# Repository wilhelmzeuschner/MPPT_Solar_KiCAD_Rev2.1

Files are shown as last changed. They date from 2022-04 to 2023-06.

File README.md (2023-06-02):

# Maximum Power Point Tracker for Solar Panels

This project was done as part of my studies at university. It's intended use case is for my [University's solar boat team](https://www.hs-emden-leer.de/studierende/fachbereiche/technik/projekte/solarboot).

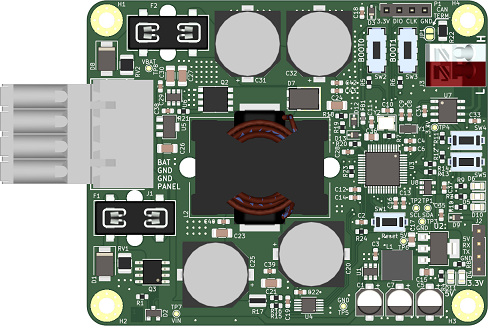
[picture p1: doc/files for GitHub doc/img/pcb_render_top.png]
render 3D Render


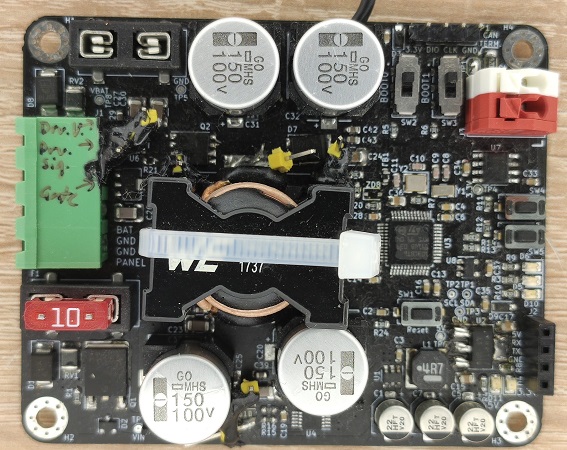
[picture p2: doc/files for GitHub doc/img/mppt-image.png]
Photo of the PCB


## Technical Overview:

- 150W input power
- Boost Converter: Uin < Uout
- STM32 Microcontroller
- CAN Communications (software support lacking as of April 2022)

## How to use this repo:

### Schematic:
The schematic can be found here: https://github.com/wilhelmzeuschner/MPPT_Solar_KiCAD_Rev2.1/blob/main/pcb/export/Schematic.pdf

### Code:
The source code is located here: https://github.com/wilhelmzeuschner/MPPT_Solar_KiCAD_Rev2.1/tree/main/code/MPPT_Main

Platform IO was used for programming, just clone the repo and open the folder / workspace. The Arduino framework was used for the firmware.

### PCB:
The PCB was designed with KiCAD V6, the files are located here: https://github.com/wilhelmzeuschner/MPPT_Solar_KiCAD_Rev2.1/tree/main/pcb/kicad_files

### Bill of Materials (BOM):
The BOM file is also provided, although some parts are not available as of April 2022 due to the semiconductor shortage.
https://github.com/wilhelmzeuschner/MPPT_Solar_KiCAD_Rev2.1/tree/main/bom

### CAD Files for a 3D-printable Case:
https://github.com/wilhelmzeuschner/MPPT_Solar_KiCAD_Rev2.1/tree/main/cad

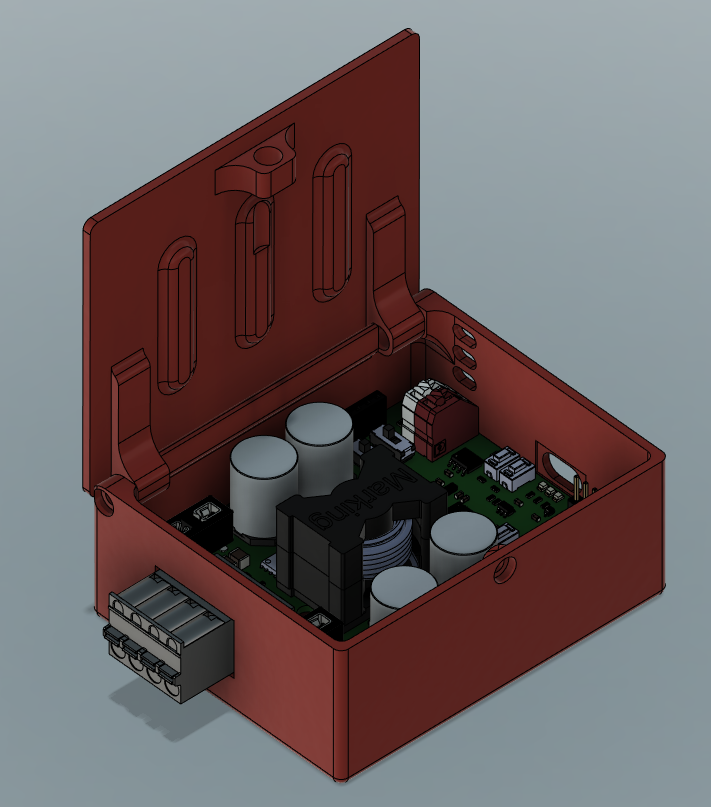
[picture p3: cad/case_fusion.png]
Case


## Further documentation:

This project was documented extensively. The technical report can be found here:
https://github.com/wilhelmzeuschner/MPPT_Solar_KiCAD_Rev2.1/blob/main/doc/latex/pdf/Projektarbeit_MPPT_Wilhelm_Zeuschner_GitHub.pdf

### License:

MIT License

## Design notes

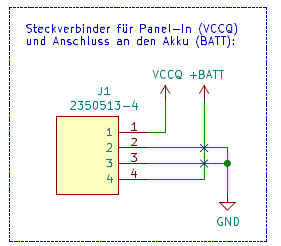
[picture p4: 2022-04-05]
doc/latex/img/schematics/all sections of the project/schem_main_pwr_conn.png

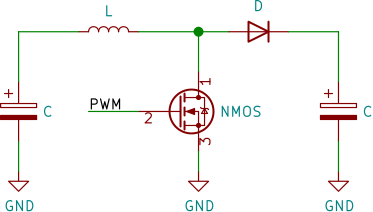
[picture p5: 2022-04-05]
doc/latex/img/schematics/boost_converter_example/g668.png

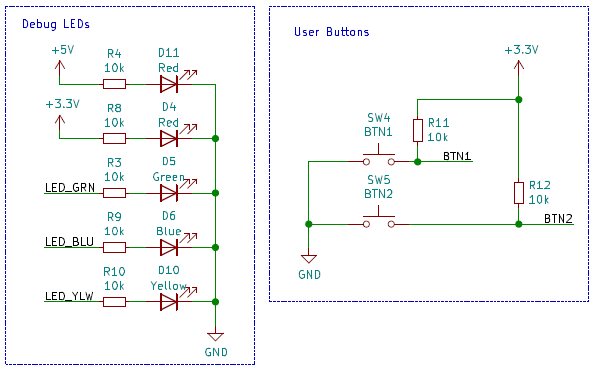
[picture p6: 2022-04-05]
doc/latex/img/schematics/all sections of the project/schem_leds_buttons.png

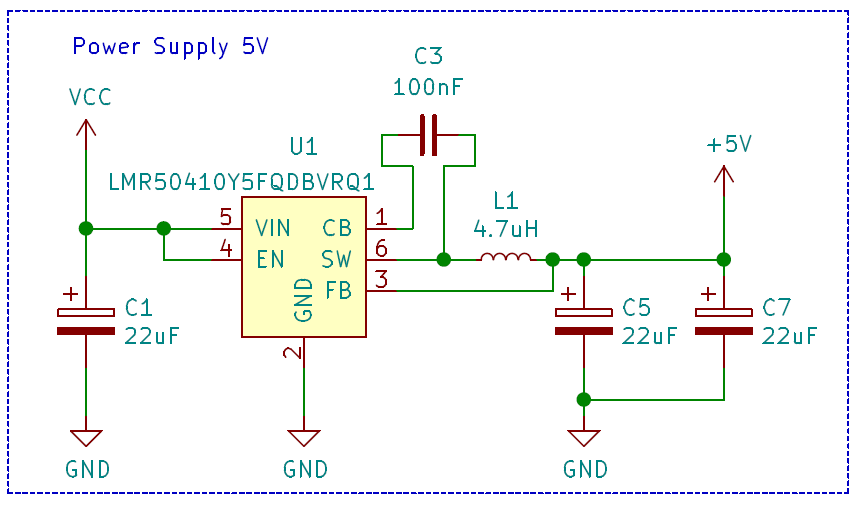
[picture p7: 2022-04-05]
doc/latex/img/schematics/all sections of the project/schem_5v_buck.png

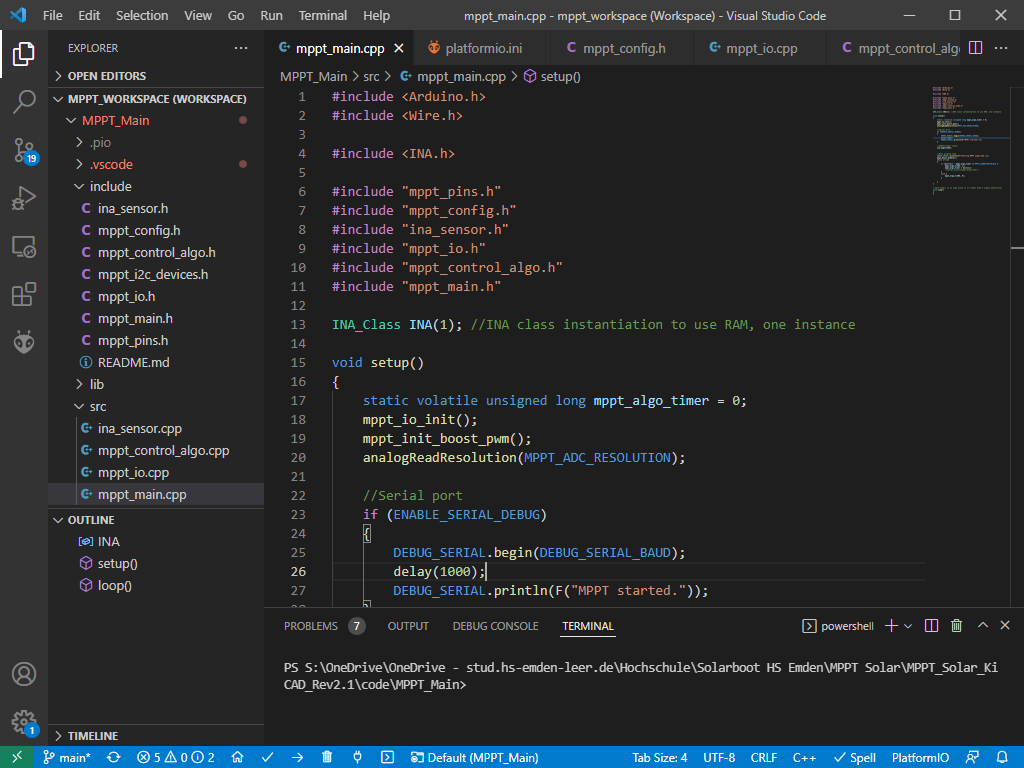
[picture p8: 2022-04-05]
doc/latex/img/sw/sw_pio_overview.png

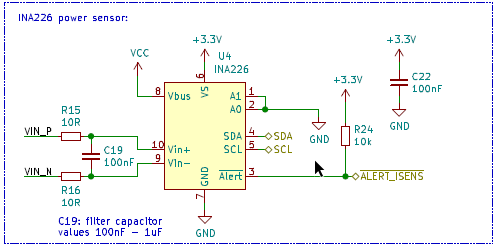
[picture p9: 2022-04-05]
doc/latex/img/schematics/all sections of the project/schem_ina.png

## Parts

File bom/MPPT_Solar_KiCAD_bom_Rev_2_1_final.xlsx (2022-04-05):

Quantity Per PCB | References | Value | Digikey Part No | Manufacturer Part Number | Note | Component | Description | Part | Footprint | Datasheet | Config
4 | C8 C9 C10 C11 | 24pF | 1276-1761-1-ND | 80-C0603C240G1HACTU |  | 1 | Unpolarized capacitor, small symbol | C_Small | C_0603_1608Metric | https://www.digikey.ch/product-detail/en/samsung-electro-mechanics/CL10C240JB8NNNC/1276-1761-1-ND/3889847
1 | C28 | 1nF | 399-12989-1-ND | C0603C102J5RACAUTO |  | 2 | Unpolarized capacitor, small symbol | C_Small | C_0603_1608Metric | https://www.digikey.ch/product-detail/en/kemet/C0603C102J5RACAUTO/399-12989-1-ND/5762271
15 | C2 C3 C4 C6 C12 C13 C14 C16 C18 C19 C22 C33 C34 C35 C37 | 100nF | 1276-CL10B104KB8NNNLCT-ND | LMK063C6104KP-F |  | 3 | Unpolarized capacitor, small symbol | C_Small | C_0603_1608Metric | https://www.digikey.ch/product-detail/en/samsung-electro-mechanics/CL10B104KB8NNNL/1276-CL10B104KB8NNNLCT-ND/10320686
3 | C15 C17 C36 | 4.7uF | 1276-1244-1-ND | 885012107013 |  | 4 | Unpolarized capacitor | C | C_0805_2012Metric | https://www.digikey.ch/product-detail/en/samsung-electro-mechanics/CL21A475KAQNNNE/1276-1244-1-ND/3889330
3 | C1 C5 C7 | 22uF | PCE5022CT-ND | 865080643008 |  | 5 | Polarized capacitor | CP | CP_Elec_5x5.9 | https://www.digikey.de/product-detail/en/panasonic-electronic-components/EEE-FT1H220AR/PCE5022CT-ND/2652077
6 | C29 C38 C39 C40 C42 C43 | 100V 100nF | 587-6323-1-ND | CL10B104KC8NNNC |  | 6 | Unpolarized capacitor, small symbol | C_Small | C_0603_1608Metric | https://www.digikey.ch/product-detail/en/taiyo-yuden/HMK107B7104MA-T/587-6323-1-ND/9949909
4 | C20 C25 C31 C32 | 100V 150uF | 565-5086-1-ND | EMHS101ARA151MKG5S |  | 7 | Polarized capacitor, small symbol | CP_Small | CAPAE1300X1650N | https://www.digikey.de/product-detail/en/united-chemi-con/EMHS800GRA241MKG5S/565-5090-1-ND/8558344
6 | C21 C23 C24 C26 C27 C30 | 100V 1uF | 587-5021-1-ND | HMK316BJ105KL-T |  | 8 | Unpolarized capacitor, small symbol | C_Small | C_1210_3225Metric_Pad1.42x2.65mm_HandSolder | https://www.digikey.ch/product-detail/en/taiyo-yuden/HMK316BJ105KL-T/587-5021-1-ND/6563864
1 | D6 | Blue | 732-4982-1-ND | 150080BS75000 |  | 9 | Light emitting diode | LED | LED_0805_2012Metric | https://www.digikey.de/product-detail/en/wÃ¼rth-elektronik/150080BS75000/732-4982-1-ND/4489910
1 | D5 | Green | 732-4983-1-ND | 150080GS75000 |  | 10 | Light emitting diode | LED | LED_0805_2012Metric | https://www.digikey.de/product-detail/en/wÃ¼rth-elektronik/150080GS75000/732-4983-1-ND/4489913
1 | D2 | MMBZ5245BLT1G | MMBZ5245BLT1GOSCT-ND | MMBZ5245BLT1G |  | 11 | Zener diode | D_Zener | D_SOT-23_ANK | https://www.digikey.de/product-detail/en/on-semiconductor/MMBZ5245BLT1G/MMBZ5245BLT1GOSCT-ND/1139860
2 | D4 D11 | Red | 732-4984-1-ND | 150080RS75000 |  | 12 | Light emitting diode | LED | LED_0805_2012Metric | https://www.digikey.de/product-detail/en/wÃ¼rth-elektronik/150080RS75000/732-4984-1-ND/4489916
2 | D1 D8 | SMBJ58A | SMBJ58ALFCT-ND | SMBJ58A |  | 13 | Zener diode | D_Zener | D_SMB | https://www.digikey.de/product-detail/en/littelfuse-inc/SMBJ58A/SMBJ58ALFCT-ND/762804
2 | D3 D9 | SS16HE | SS16HECT-ND | SS16HE |  | 14 | Schottky diode, small symbol | D_Schottky_Small | D_SOD-323_HandSoldering | https://www.digikey.de/product-detail/en/on-semiconductor/SS16HE/SS16HECT-ND/6009714
2 | D7 | TSPB20U80S S1G | TSPB20U80SS1GCT-ND | TSPB20U80S S1G |  | 15 | Schottky diode, anode on pins 1 and 2 | V15P8HM3_A_H | TO-277A | https://www.digikey.de/product-detail/en/taiwan-semiconductor-corporation/TSPB20U80S-S1G/TSPB20U80SS1GCT-ND/7360696
1 | D10 | Yellow | 732-4987-1-ND | 150080YS75000 |  | 16 | Light emitting diode | LED | LED_0805_2012Metric | https://www.digikey.de/product-detail/en/wÃ¼rth-elektronik/150080YS75000/732-4987-1-ND/4489925
2 | F1 F2 | 3588TR | 36-3588CT-ND | 3588TR | Fuse: 0297010.WXNV https://www.digikey.de/product-detail/en/littelfuse-inc/0297010-WXNV/F991-ND/146591 | 17 |  | 3588TR | 3588TR | https://www.digikey.de/product-detail/en/keystone-electronics/3588TR/36-3588CT-ND/4772085
1 | FB1 | Ferrite_Bead | 490-9701-1-ND | BLM18TG102TN1D |  | 18 | Ferrite bead, small symbol | Ferrite_Bead_Small | L_0603_1608Metric | https://www.digikey.de/product-detail/en/murata-electronics/BLM18TG102TN1D/490-9701-1-ND/4934841
1 | J1 | 2350513-4 | A145374-ND | 2350513-4 | Counterpart: A145365-ND (2350397-4) | 19 | Pluggable Terminal Blocks 4pos Header 90 Deg 5.0mmTail Lgth 4.5mm | 2350513-4 | SHDRRA4W110P0X500_1X4_2160X830X1230P | https://www.digikey.de/product-detail/en/te-connectivity-amp-connectors/2350513-4/A145374-ND/10415924
1 | J3 | CAN | 277-8591-ND | 1713017 |  | 20 | Generic connector, single row, 01x02, script generated (kicad-library-utils/schlib/autogen/connector/) | Conn_01x02 | 1713017 | https://www.digikey.de/product-detail/en/phoenix-contact/1713017/277-8591-ND/2513977
1 | J2 | UART | 2057-RS1-04-G-ND | RS1-04-G |  | 21 | Generic connector, single row, 01x04, script generated (kicad-library-utils/schlib/autogen/connector/) | Conn_01x04 | PinHeader_1x04_P2.54mm_Vertical | https://www.digikey.de/product-detail/en/adam-tech/RS1-04-G/2057-RS1-04-G-ND/9829303
1 | L1 | 4.7uH | 587-2943-1-ND | NRS6028T4R7MMGK |  | 22 | Inductor, small symbol | L_Small | 60x60mm_Inductor | https://www.digikey.de/product-detail/en/taiyo-yuden/NRS6028T4R7MMGK/587-2943-1-ND/2666048
1 | L2 | 68uH | 732-11708-ND | 74437429203680 |  | 23 | 74437429203680 Inductor with ferrite core | 68uH | 74437429203680 | https://www.digikey.de/products/en?keywords=74437429203680
1 | P1 | SWD_Prog_port | 2057-RS1-04-G-ND | RS1-04-G |  | 24 |  | SWD_Prog_port | PinSocket_1x04_P2.54mm_Vertical | https://www.digikey.de/product-detail/en/adam-tech/RS1-04-G/2057-RS1-04-G-ND/9829303
1 | Q1 | ATP302 | ATP302-TL-HOSCT-ND | ATP302-TL-H |  | 25 | P-MOSFET transistor, gate/drain/source | Q_PMOS_GDS | ATPAK-2 | https://www.digikey.de/product-detail/en/on-semiconductor/ATP302-TL-H/ATP302-TL-HOSCT-ND/5801683
2 | Q2 | TPH2R408QM,L1Q | 264-TPH2R408QML1QCT-ND | TPH2R408QM,L1Q |  | 26 |  | TPH2R608NH | SOP_ADVANCE | https://www.digikey.de/product-detail/en/toshiba-semiconductor-and-storage/TPH2R408QM-L1Q/264-TPH2R408QML1QCT-ND/11658238
1 | R21 | 0R | 311-0.0HRCT-ND | RC0603FR-070RL |  | 27 | Resistor, small symbol | R_Small | R_0603_1608Metric | https://www.digikey.de/product-detail/en/yageo/RC0603FR-070RL/311-0-0HRCT-ND/4340584
1 | R17 | 10mR | CFG0612-FX-R010ELFCT-ND | CFG0612-FX-R010ELF |  | 28 | Resistor | R | R_0612_1632Metric | https://www.digikey.de/product-detail/en/bourns-inc/CFG0612-FX-R010ELF/CFG0612-FX-R010ELFCT-ND/9924214
3 | R15 R16 R23 | 10R | RMCF0603FT10R0CT-ND | RMCF0603FT10R0 |  | 29 | Resistor, small symbol | R_Small | R_0603_1608Metric | https://www.digikey.de/product-detail/en/stackpole-electronics-inc/RMCF0603FT10R0/RMCF0603FT10R0CT-ND/1942943
1 | R22 | 120R | 311-120FRCT-ND | RC1206FR-07120RL |  | 30 | Resistor, small symbol | R_Small | R_1206_3216Metric | https://www.digikey.de/product-detail/en/yageo/RC1206FR-07120RL/311-120FRCT-ND/731470
1 | R20 | 1k | 541-3949-1-ND | CRCW06031K00FKEAC |  | 31 | Resistor, small symbol | R_Small | R_0603_1608Metric | https://www.mouser.de/ProductDetail/Vishay-Dale/CRCW06031K00FKEAC
15 | R1 R3 R4 R5 R6 R8 R9 R10 R11 R12 R13 R14 R18 R19 R24 | 10k | 311-10.0KHRCT-ND | RC0603FR-0710KL |  | 32 | Resistor, small symbol | R_Small | R_0603_1608Metric | https://www.mouser.de/ProductDetail/Yageo/RC0603FR-0710KL
1 | R7 | 1M | 311-1.00MHRCT-ND | RC0603FR-071ML |  | 33 | Resistor, small symbol | R_Small | R_0603_1608Metric | https://www.mouser.de/ProductDetail/Yageo/RC0603FR-071ML
2 | RV1 RV2 | V60MLA1210N | F3830CT-ND | V60MLA1210NH |  | 34 | Voltage dependent resistor | Varistor | R_1210_3225Metric_Pad1.42x2.65mm_HandSolder | https://www.digikey.de/product-detail/en/littelfuse-inc/V60MLA1210NH/F3830CT-ND/2627750
1 | SW4 | BTN1 | CKN12317-1-ND | CKN12317-1-ND |  | 35 | Push button switch, generic, two pins | SW_Push | SW_SPST_EVQPE1 | https://www.digikey.de/product-detail/en/c-k/PTS636-SM43J-SMTR-LFS/CKN12317-1-ND/10071752
1 | SW5 | BTN2 | CKN12317-1-ND | CKN12317-1-ND |  | 36 | Push button switch, generic, two pins | SW_Push | SW_SPST_EVQPE1 | https://www.digikey.de/product-detail/en/c-k/PTS636-SM43J-SMTR-LFS/CKN12317-1-ND/10071752
1 | SW2 | Boot0 | CKN10723CT-ND | JS202011JCQN |  | 37 | Switch, single pole double throw | SW_SPDT | SW_JS202011JCQN | https://www.digikey.de/product-detail/en/c-k/JS202011JCQN/CKN10723CT-ND/6137637
1 | SW3 | Boot1 | CKN10723CT-ND | JS202011JCQN |  | 38 | Switch, single pole double throw | SW_SPDT | SW_JS202011JCQN | https://www.digikey.de/product-detail/en/c-k/JS202011JCQN/CKN10723CT-ND/6137637
1 | SW1 | Reset | CKN12317-1-ND | CKN12317-1-ND |  | 39 | Push button switch, generic, two pins | SW_Push | SW_SPST_EVQPE1 | https://www.digikey.de/product-detail/en/c-k/PTS636-SM43J-SMTR-LFS/CKN12317-1-ND/10071752
2 | U8 | 24FC01T-I_OT | 24FC01T-I/OTCT-ND | 24FC01T-I/OT |  | 40 | 1KB I2C EEPROM 1MHZ 1.7-5.5V 5-S | 24FC01T-I_OT | SOT-23-5 | https://www.digikey.de/product-detail/en/microchip-technology/24FC01T-I-OT/24FC01T-I-OTCT-ND/9867141
2 | U2 | AP2114HA-3.3TRG1 | AP2114HA-3.3TRG1DICT-ND | AP2114HA-3.3TRG1 |  | 41 |  | AP2114H-3.3TRG1 | SOT-223-3_TabPin2 | https://www.digikey.de/product-detail/en/diodes-incorporated/AP2114HA-3-3TRG1/AP2114HA-3-3TRG1DICT-ND/8545749
2 | U4 | INA226 | 296-29034-1-ND | INA226AIDGSR |  | 42 | High-Side or Low-Side Measurement, Bi-Directional Current and Power Monitor (0-36V) with I2C Compatible Interface, VSSOP-10 | INA226 | VSSOP-10_3x3mm_P0.5mm | https://www.digikey.de/product-detail/en/texas-instruments/INA226AIDGSR/296-29034-1-ND/2687118
2 | U5 | L78L18_SOT89 | 497-7280-1-ND | L78L18ACUTR |  | 43 | Positive 100mA 30V Linear Regulator, Fixed Output 18V, SOT-89 | L78L18_SOT89 | SOT-89-3 | https://www.digikey.de/product-detail/en/stmicroelectronics/L78L18ACUTR/497-7280-1-ND/1883360
2 | U1 | LMR50410Y5FQDBVRQ1 | 296-LMR50410Y5FQDBVRQ1CT-ND | LMR50410Y5FQDBVRQ1 |  | 44 | Buck Switching Regulator IC Positive Fixed 5V 1 Output 1A SOT-23-6 | LMR50410Y5FQDBVRQ1 | SOT-23-6 | https://www.digikey.de/product-detail/en/texas-instruments/LMR50410Y5FQDBVRQ1/296-LMR50410Y5FQDBVRQ1CT-ND/13563137
2 | U7 | NCV7344D13R2G | NCV7344D13R2GOSCT-ND | NCV7344D13R2G |  | 45 | 1/1 Transceiver Half CANbus 8-SOIC | NCV7344D13R2G | SOIC-8_3.9x4.9mm_P1.27mm | https://www.digikey.de/product-detail/en/on-semiconductor/NCV7344D13R2G/NCV7344D13R2GOSCT-ND/9923536
2 | U3 | STM32F103CBT6TR | 497-17380-1-ND | STM32F103CBT6TR |  | 46 | ARM Cortex-M3 MCU, 128KB flash, 20KB RAM, 72MHz, 2-3.6V, 37 GPIO, LQFP-48 | STM32F103CBTx | LQFP-48_7x7mm_P0.5mm | https://www.digikey.de/product-detail/en/stmicroelectronics/STM32F103CBT6TR/497-17380-1-ND/7650389
2 | U6 | UCC27531DBVR | 296-35581-1-ND | UCC27531DBVR |  | 47 | UCC2753x 2.5-A and 5-A, 35-VMAX VDD FET and IGBT Single-Gate Driver | UCC27531DBVR | SOT-23-6 | https://www.digikey.de/product-detail/en/texas-instruments/UCC27531DBVR/296-35581-1-ND/3830022
1 | Y1 | 32.768kHz | SER4076CT-ND | FC-135R 32.7680KF-A3 |  | 48 | Two pin crystal | Crystal | Crystal_SMD_MicroCrystal_CC7V-T1A-2Pin_3.2x1.5mm | https://www.digikey.de/product-detail/en/epson/FC-135R-32-7680KF-A3/SER4076CT-ND/5604232
1 | Y2 | 8MHz | 50-ECS-80-12-33Q-GN-CT-ND | ECS-80-12-33Q-GN-TR |  | 49 | Four pin crystal, GND on pins 2 and 4 | Crystal_GND24 | Crystal_SMD_3225-4Pin_3.2x2.5mm | https://www.digikey.de/product-detail/en/ecs-inc/ECS-80-12-33Q-GN-TR/50-ECS-80-12-33Q-GN-CT-ND/12088513
1 | ZD8 | MM3Z3V3T1G | MM3Z3V3T1GOSCT-ND | MM3Z3V3T1G |  | 50 | Zener diode, small symbol | D_Zener_Small | D_SOD-323 | https://www.digikey.de/product-detail/en/on-semiconductor/MM3Z3V3T1G/MM3Z3V3T1GOSCT-ND/2623467
3 | NA | 0297010.WXNV | F991-ND | 0297010.WXNV | 10A Fuse, 1 extra
2 | NA | 2350397-4 | A145365-ND | 2350397-4 | 4 Position Terminal Block Plug, Female Sockets 0.197" (5.00mm) 180° Free Hanging (In-Line), not on PCB, 1 extra
1 | NA | SMD291AX | SMD291AX-ND | SMD291AX | Leaded No-Clean Solder Paste Sn63Pb37 (63/37) Syringe, 0.53 oz (15g), 5cc
This BOM was created manually and not via the automated export

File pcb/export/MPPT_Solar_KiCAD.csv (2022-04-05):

Reference | Quantity | Value | Footprint | Datasheet | Digikey Part No | Manufacturer Part Number | Config | Note | Description | Digi-Key Part No | Manufacturer Part No
C15 C17 C36 | 3 | 4.7uF | Capacitor_SMD:C_0805_2012Metric | https://www.digikey.ch/product-detail/en/samsung-electro-mechanics/CL21A475KAQNNNE/1276-1244-1-ND/3889330 | 1276-1244-1-ND | 885012107013
C20 C25 C31 C32 | 4 | 100V 150uF | MPPT_Solar_KiCAD:CAPAE1300X1650N | https://www.digikey.de/product-detail/en/united-chemi-con/EMHS800GRA241MKG5S/565-5090-1-ND/8558344 | 565-5086-1-ND | EMHS101ARA151MKG5S
C21 C23 C24 C26 C27 C30 | 6 | 100V 1uF | Capacitor_SMD:C_1206_3216Metric | https://www.digikey.ch/product-detail/en/taiyo-yuden/HMK316BJ105KL-T/587-5021-1-ND/6563864 | 587-5021-1-ND | HMK316BJ105KL-T
C28 | 1 | 1nF | Capacitor_SMD:C_0603_1608Metric | https://www.digikey.ch/product-detail/en/kemet/C0603C102J5RACAUTO/399-12989-1-ND/5762271 | 399-12989-1-ND | C0603C102J5RACAUTO
C29 C38 C39 C40 C42 C43 | 6 | 100V 100nF | Capacitor_SMD:C_0603_1608Metric | https://www.digikey.ch/product-detail/en/taiyo-yuden/HMK107B7104MA-T/587-6323-1-ND/9949909 | 587-6323-1-ND | CL10B104KC8NNNC
C2 C3 C4 C6 C12 C13 C14 C16 C18 C19 C22 C33 C34 C35 C37 | 15 | 100nF | Capacitor_SMD:C_0603_1608Metric | https://www.digikey.ch/product-detail/en/samsung-electro-mechanics/CL10B104KB8NNNL/1276-CL10B104KB8NNNLCT-ND/10320686 | 1276-CL10B104KB8NNNLCT-ND | LMK063C6104KP-F
C1 C5 C7 | 3 | 22uF | Capacitor_SMD:CP_Elec_5x5.9 | https://www.digikey.de/product-detail/en/panasonic-electronic-components/EEE-FT1H220AR/PCE5022CT-ND/2652077 | PCE5022CT-ND | 865080643008
C8 C9 C10 C11 | 4 | 24pF | Capacitor_SMD:C_0603_1608Metric | https://www.digikey.ch/product-detail/en/samsung-electro-mechanics/CL10C240JB8NNNC/1276-1761-1-ND/3889847 | 1276-1761-1-ND | 80-C0603C240G1HACTU
D1 D8 | 2 | SMBJ58A | Diode_SMD:D_SMB | https://www.digikey.de/product-detail/en/littelfuse-inc/SMBJ58A/SMBJ58ALFCT-ND/762804 | SMBJ58ALFCT-ND | SMBJ58A
D10 | 1 | Yellow | LED_SMD:LED_0805_2012Metric | https://www.digikey.de/product-detail/en/würth-elektronik/150080YS75000/732-4987-1-ND/4489925 | 732-4987-1-ND | 150080YS75000
D2 D14 | 2 | MMBZ5245BLT1G | Diode_SMD:D_SOT-23_ANK | https://www.digikey.de/product-detail/en/on-semiconductor/MMBZ5245BLT1G/MMBZ5245BLT1GOSCT-ND/1139860 | MMBZ5245BLT1GOSCT-ND | MMBZ5245BLT1G
D3 D9 D12 D13 | 4 | SS16HE | Diode_SMD:D_SOD-323 | https://www.digikey.de/product-detail/en/on-semiconductor/SS16HE/SS16HECT-ND/6009714 | SS16HECT-ND | SS16HE
D4 D11 | 2 | Red | LED_SMD:LED_0805_2012Metric | https://www.digikey.de/product-detail/en/würth-elektronik/150080RS75000/732-4984-1-ND/4489916 | 732-4984-1-ND | 150080RS75000
D5 | 1 | Green | LED_SMD:LED_0805_2012Metric | https://www.digikey.de/product-detail/en/würth-elektronik/150080GS75000/732-4983-1-ND/4489913 | 732-4983-1-ND | 150080GS75000
D6 | 1 | Blue | LED_SMD:LED_0805_2012Metric | https://www.digikey.de/product-detail/en/würth-elektronik/150080BS75000/732-4982-1-ND/4489910 | 732-4982-1-ND | 150080BS75000
D7 | 1 | TSPB20U80S S1G | Package_TO_SOT_SMD:TO-277A | https://www.digikey.de/product-detail/en/taiwan-semiconductor-corporation/TSPB20U80S-S1G/TSPB20U80SS1GCT-ND/7360696 | TSPB20U80SS1GCT-ND | TSPB20U80S S1G
F1 F2 | 2 | 3588TR | MPPT_Solar_KiCAD:3588TR | https://www.digikey.de/product-detail/en/keystone-electronics/3588TR/36-3588CT-ND/4772085 | 36-3588CT-ND | 3588TR |  | Fuse: 0297010.WXNV https://www.digikey.de/product-detail/en/littelfuse-inc/0297010-WXNV/F991-ND/146591
FB1 | 1 | Ferrite_Bead | Inductor_SMD:L_0603_1608Metric | https://www.digikey.de/product-detail/en/murata-electronics/BLM18TG102TN1D/490-9701-1-ND/4934841 | 490-9701-1-ND | BLM18TG102TN1D
G1 | 1 | Logo_HS_Emden | MPPT_Solar_KiCAD:HS_Logo | ~ |  |  | dnf
H1 H2 H3 H4 | 4 | MountingHole | MountingHole:MountingHole_3.2mm_M3_Pad_Via | ~ |  |  | dnf
J1 | 1 | 2350513-4 | SHDRRA4W110P0X500_1X4_2160X830X1230P | https://www.digikey.de/product-detail/en/te-connectivity-amp-connectors/2350513-4/A145374-ND/10415924 | A145374-ND | 2350513-4 |  | Counterpart: A145365-ND (2350397-4) | Pluggable Terminal Blocks 4pos Header 90 Deg 5.0mmTail Lgth 4.5mm
J2 | 1 | UART | Connector_PinHeader_2.54mm:PinHeader_1x04_P2.54mm_Vertical | https://www.digikey.de/product-detail/en/adam-tech/RS1-04-G/2057-RS1-04-G-ND/9829303 | 2057-RS1-04-G-ND | RS1-04-G
J3 | 1 | CAN | MPPT_Solar_KiCAD:1713017 | https://www.digikey.de/product-detail/en/phoenix-contact/1713017/277-8591-ND/2513977 | 277-8591-ND | 1713017
JP1 | 1 | CAN_TERM | Jumper:SolderJumper-2_P1.3mm_Open_RoundedPad1.0x1.5mm | ~ |  |  | dnf
L1 | 1 | 4.7uH | MPPT_Solar_KiCAD:60x60mm_Inductor | https://www.digikey.de/product-detail/en/taiyo-yuden/NRS6028T4R7MMGK/587-2943-1-ND/2666048 | 587-2943-1-ND | NRS6028T4R7MMGK
L2 | 1 | 68uH | MPPT_Solar_KiCAD:74437429203680 | https://www.digikey.de/products/en?keywords=74437429203680 | 732-11708-ND | 74437429203680
NT1 | 1 | Net-Tie_2 | NetTie:NetTie-2_SMD_Pad0.5mm | ~
P1 | 1 | SWD_Prog_port | Connector_PinSocket_2.54mm:PinSocket_1x04_P2.54mm_Vertical | https://www.digikey.de/product-detail/en/adam-tech/RS1-04-G/2057-RS1-04-G-ND/9829303 | 2057-RS1-04-G-ND | RS1-04-G
Q1 | 1 | DMP6050 | Package_SO:SO-8_3.9x4.9mm_P1.27mm
Q2 | 1 | TPH2R408QM,L1Q | MPPT_Solar_KiCAD:SOP_ADVANCE | https://www.digikey.de/product-detail/en/toshiba-semiconductor-and-storage/TPH2R408QM-L1Q/264-TPH2R408QML1QCT-ND/11658238 | 264-TPH2R408QML1QCT-ND | TPH2R408QM,L1Q
Q3 | 1 | DMP4015SSS | Package_SO:SO-8_3.9x4.9mm_P1.27mm | https://www.digikey.de/product-detail/en/diodes-incorporated/DMP4015SSS-13/DMP4015SSS-13DICT-ND/5218252 |  |  |  |  |  | DMP4015SSS-13DICT-ND | DMP4015SSS-13
R15 R16 R23 | 3 | 10R | Resistor_SMD:R_0603_1608Metric | https://www.digikey.de/product-detail/en/stackpole-electronics-inc/RMCF0603FT10R0/RMCF0603FT10R0CT-ND/1942943 | RMCF0603FT10R0CT-ND | RMCF0603FT10R0
R17 | 1 | 10mR | Resistor_SMD:R_0612_1632Metric | https://www.digikey.de/product-detail/en/bourns-inc/CFG0612-FX-R010ELF/CFG0612-FX-R010ELFCT-ND/9924214 | CFG0612-FX-R010ELFCT-ND | CFG0612-FX-R010ELF
R20 | 1 | 1k | Resistor_SMD:R_0603_1608Metric | https://www.mouser.de/ProductDetail/Vishay-Dale/CRCW06031K00FKEAC | 541-3949-1-ND | CRCW06031K00FKEAC
R21 | 1 | 0R | Resistor_SMD:R_0603_1608Metric | https://www.digikey.de/product-detail/en/yageo/RC0603FR-070RL/311-0-0HRCT-ND/4340584 | 311-0.0HRCT-ND | RC0603FR-070RL
R22 | 1 | 120R | Resistor_SMD:R_1206_3216Metric | https://www.digikey.de/product-detail/en/yageo/RC1206FR-07120RL/311-120FRCT-ND/731470 | 311-120FRCT-ND | RC1206FR-07120RL
R1 R2 R3 R4 R5 R6 R8 R9 R10 R11 R12 R13 R14 R18 R19 R24 | 16 | 10k | Resistor_SMD:R_0603_1608Metric | https://www.mouser.de/ProductDetail/Yageo/RC0603FR-0710KL | 311-10.0KHRCT-ND | RC0603FR-0710KL
R7 | 1 | 1M | Resistor_SMD:R_0603_1608Metric | https://www.mouser.de/ProductDetail/Yageo/RC0603FR-071ML | 311-1.00MHRCT-ND | RC0603FR-071ML
RV1 | 1 | V60MLA1210N | Resistor_SMD:R_1210_3225Metric | https://www.digikey.de/product-detail/en/littelfuse-inc/V60MLA1210NH/F3830CT-ND/2627750 | F3830CT-ND | V60MLA1210NH
RV2 | 1 | V60MLA1210N | Resistor_SMD:R_1210_3225Metric | https://www.digikey.de/product-detail/en/littelfuse-inc/V60MLA1210NH/F3830CT-ND/2627750 | F3830CT-ND | V60MLA1210NH
SW1 | 1 | Reset | MPPT_Solar_KiCAD:SW_SPST_EVQPE1 | https://www.digikey.de/product-detail/en/c-k/PTS636-SM43J-SMTR-LFS/CKN12317-1-ND/10071752 | CKN12317-1-ND | CKN12317-1-ND
SW2 | 1 | Boot0 | MPPT_Solar_KiCAD:SW_JS202011JCQN | https://www.digikey.de/product-detail/en/c-k/JS202011JCQN/CKN10723CT-ND/6137637 | CKN10723CT-ND | JS202011JCQN
SW3 | 1 | Boot1 | MPPT_Solar_KiCAD:SW_JS202011JCQN | https://www.digikey.de/product-detail/en/c-k/JS202011JCQN/CKN10723CT-ND/6137637 | CKN10723CT-ND | JS202011JCQN
SW4 | 1 | BTN1 | MPPT_Solar_KiCAD:SW_SPST_EVQPE1 | https://www.digikey.de/product-detail/en/c-k/PTS636-SM43J-SMTR-LFS/CKN12317-1-ND/10071752 | CKN12317-1-ND | CKN12317-1-ND
SW5 | 1 | BTN2 | MPPT_Solar_KiCAD:SW_SPST_EVQPE1 | https://www.digikey.de/product-detail/en/c-k/PTS636-SM43J-SMTR-LFS/CKN12317-1-ND/10071752 | CKN12317-1-ND | CKN12317-1-ND
TP1 | 1 | SDA | TestPoint:TestPoint_Pad_D1.0mm | ~ |  |  | dnf
TP10 | 1 | USB_DP | TestPoint:TestPoint_Pad_D1.0mm | ~ |  |  | dnf
TP11 | 1 | USB_DN | TestPoint:TestPoint_Pad_D1.0mm | ~ |  |  | dnf
TP2 | 1 | SCL | TestPoint:TestPoint_Pad_D1.0mm | ~ |  |  | dnf
TP3 TP5 TP9 | 3 | GND | TestPoint:TestPoint_Pad_D1.0mm | ~ |  |  | dnf
TP4 | 1 | 3.3V | TestPoint:TestPoint_Pad_D1.0mm | ~ |  |  | dnf
TP6 | 1 | 5V | TestPoint:TestPoint_Pad_D1.0mm | ~ |  |  | dnf
TP7 | 1 | VIN | TestPoint:TestPoint_Pad_D1.0mm | ~ |  |  | dnf
TP8 | 1 | VBAT | TestPoint:TestPoint_Pad_D1.0mm | ~ |  |  | dnf
U1 | 1 | LMR50410Y5FQDBVRQ1 | Package_TO_SOT_SMD:SOT-23-6 | https://www.digikey.de/product-detail/en/texas-instruments/LMR50410Y5FQDBVRQ1/296-LMR50410Y5FQDBVRQ1CT-ND/13563137 | 296-LMR50410Y5FQDBVRQ1CT-ND | LMR50410Y5FQDBVRQ1
U2 | 1 | AP2111H-3.3TRG1 | Package_TO_SOT_SMD:SOT-223 | https://www.digikey.de/product-detail/en/diodes-incorporated/AP2111H-3-3TRG1/AP2111H-3-3TRG1DICT-ND/4505138 | AP2111H-3.3TRG1DICT-ND | AP2111H-3.3TRG1
U3 | 1 | STM32F103CBT6TR | Package_QFP:LQFP-48_7x7mm_P0.5mm | https://www.digikey.de/product-detail/en/stmicroelectronics/STM32F103CBT6TR/497-17380-1-ND/7650389 | 497-17380-1-ND | STM32F103CBT6TR
U4 | 1 | INA226 | Package_SO:VSSOP-10_3x3mm_P0.5mm | https://www.digikey.de/product-detail/en/texas-instruments/INA226AIDGSR/296-29034-1-ND/2687118 | 296-29034-1-ND | INA226AIDGSR
U5 | 1 | L78L18_SOT89 | Package_TO_SOT_SMD:SOT-89-3 | https://www.digikey.de/product-detail/en/stmicroelectronics/L78L18ACUTR/497-7280-1-ND/1883360 | 497-7280-1-ND | L78L18ACUTR
U6 | 1 | UCC27531DBVR | Package_TO_SOT_SMD:SOT-23-6 | https://www.digikey.de/product-detail/en/texas-instruments/UCC27531DBVR/296-35581-1-ND/3830022 | 296-35581-1-ND | UCC27531DBVR
U7 | 1 | NCV7344D13R2G | Package_SO:SOIC-8_3.9x4.9mm_P1.27mm | https://www.digikey.de/product-detail/en/on-semiconductor/NCV7344D13R2G/NCV7344D13R2GOSCT-ND/9923536 | NCV7344D13R2GOSCT-ND | NCV7344D13R2G
U8 | 1 | 24FC01T-I_OT | Package_TO_SOT_SMD:SOT-23-5 | https://www.digikey.de/product-detail/en/microchip-technology/24FC01T-I-OT/24FC01T-I-OTCT-ND/9867141 | 24FC01T-I/OTCT-ND | 24FC01T-I/OT
Y1 | 1 | 32.768kHz | Crystal:Crystal_SMD_MicroCrystal_CC7V-T1A-2Pin_3.2x1.5mm | https://www.digikey.de/product-detail/en/epson/FC-135R-32-7680KF-A3/SER4076CT-ND/5604232 | SER4076CT-ND | FC-135R 32.7680KF-A3
Y2 | 1 | 8MHz | Crystal:Crystal_SMD_3225-4Pin_3.2x2.5mm | https://www.digikey.de/product-detail/en/ecs-inc/ECS-80-12-33Q-GN-TR/50-ECS-80-12-33Q-GN-CT-ND/12088513 | 50-ECS-80-12-33Q-GN-CT-ND | ECS-80-12-33Q-GN-TR

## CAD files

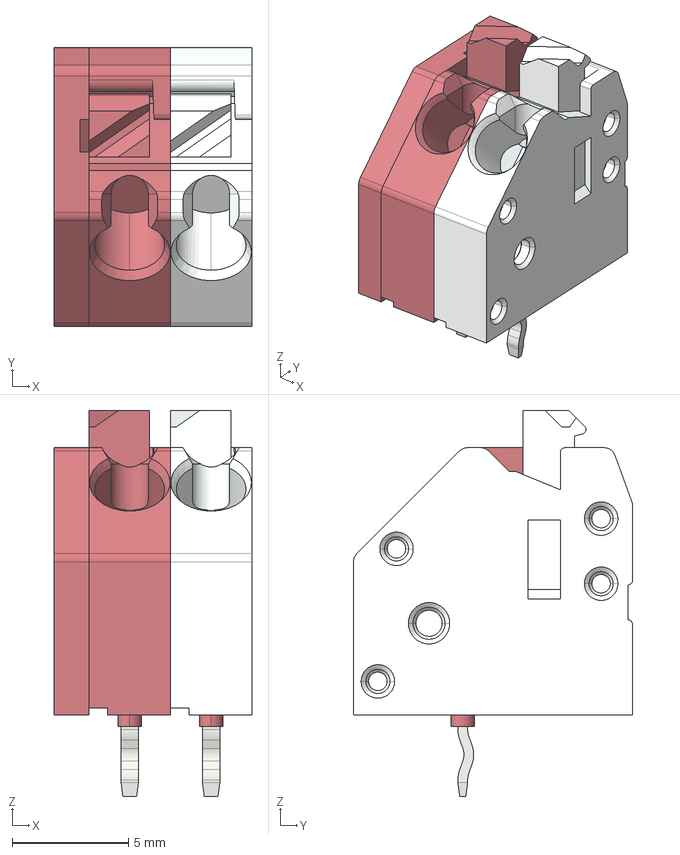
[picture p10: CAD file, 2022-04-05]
pcb/kicad_files/mppt_3d_models/pxc_1713017_03_PTSA-1-5-2-3-5-F-RD-WH-NZ02_3D.stp
8.50 x 12.0 x 16.6 mm
PTSA1_5-2-3_5-F
PTSA1_5-2-3_5-F-1
PTSA1_5-Dkl
Bohrloch2
Bohrloch1

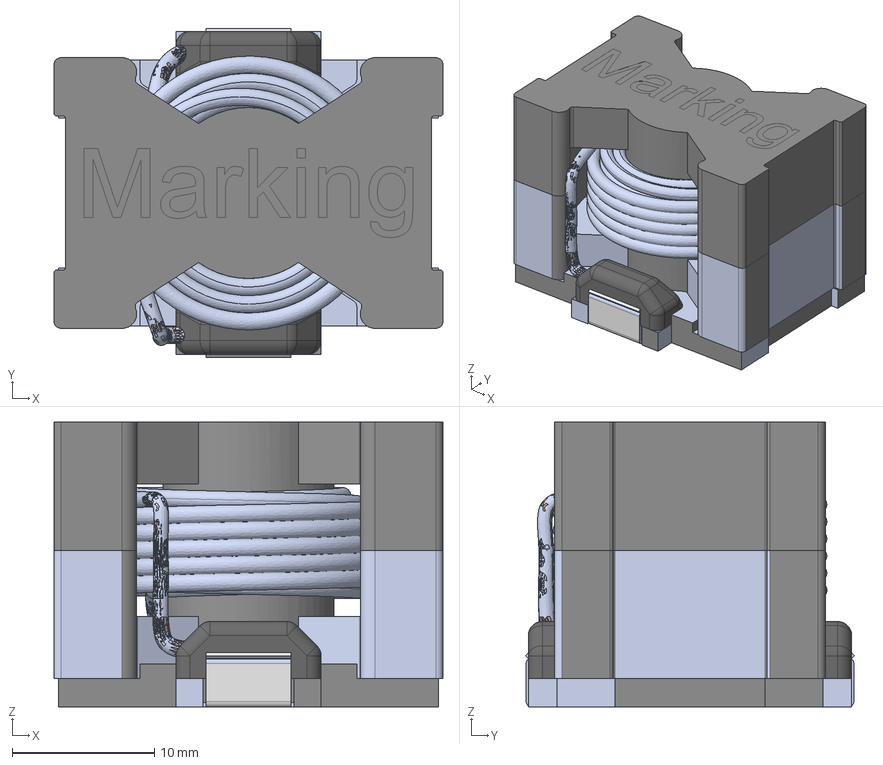
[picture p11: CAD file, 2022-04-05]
pcb/kicad_files/mppt_3d_models/Download_STP_WE-HCF-2920-Litz_rev1.stp
27.3 x 23.1 x 20.0 mm
Base
Core
Core-oa0
Contact x 2
Wire
Glue_front x 6
Glue_back x 6

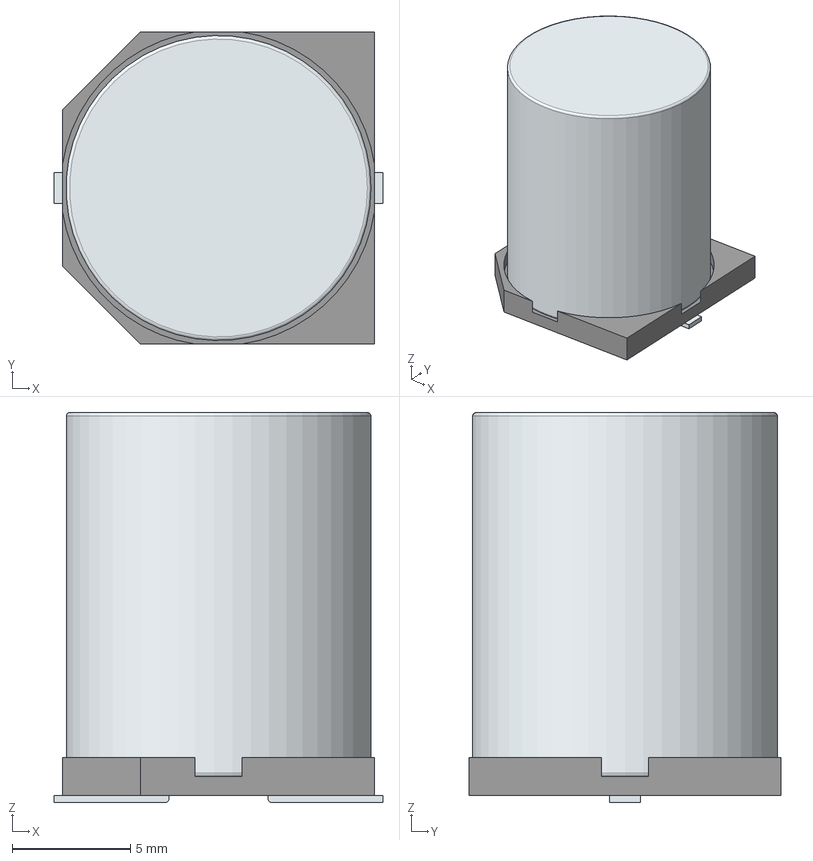
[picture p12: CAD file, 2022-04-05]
pcb/kicad_files/mppt_3d_models/EMHS800GRA241MKG5S.stp
13.9 x 13.2 x 16.5 mm
Base
Pin1Fillet
Pin2Fillet

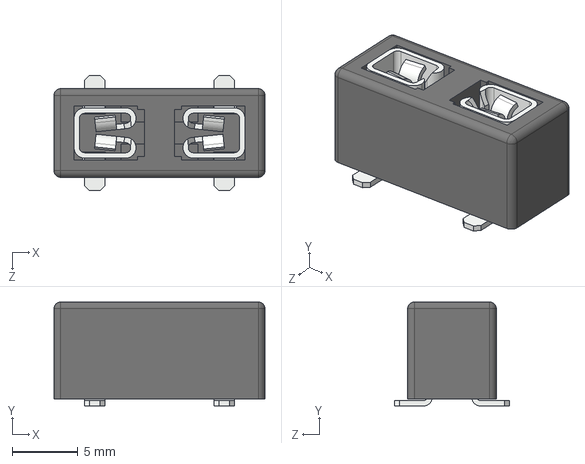
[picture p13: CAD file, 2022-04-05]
pcb/kicad_files/mppt_3d_models/keystone-PN3588TR.STEP
16.0 x 7.88 x 8.76 mm

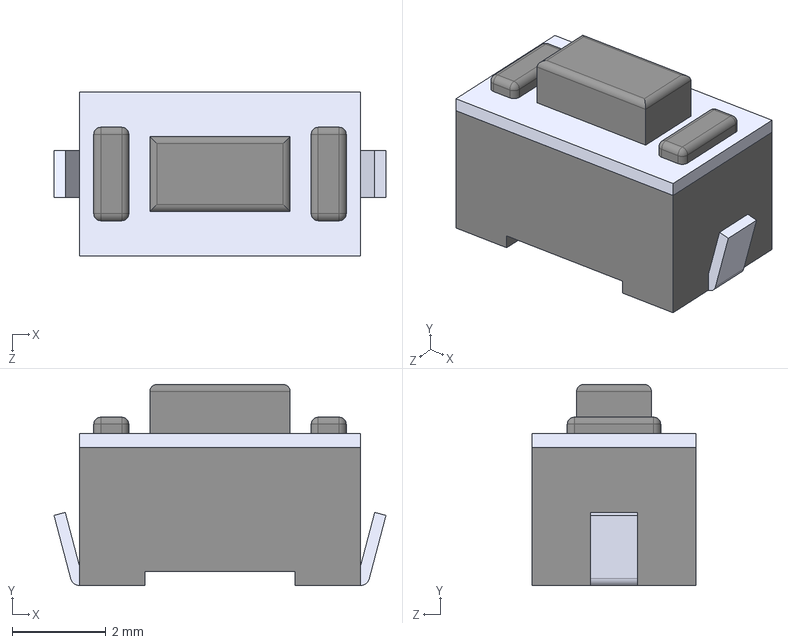
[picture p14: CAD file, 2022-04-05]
pcb/kicad_files/mppt_3d_models/PTS636 SM43J SMTR LFS--3DModel-STEP-56544.STEP
7.10 x 4.30 x 3.50 mm

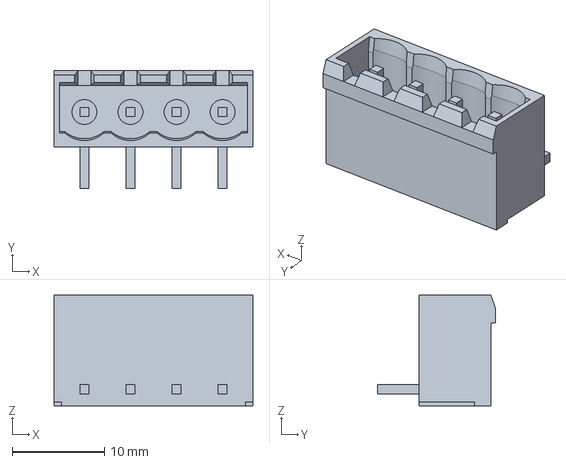
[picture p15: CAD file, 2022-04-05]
pcb/kicad_files/mppt_3d_models/c-2350513-4-1-3d.stp
21.6 x 12.8 x 12.0 mm

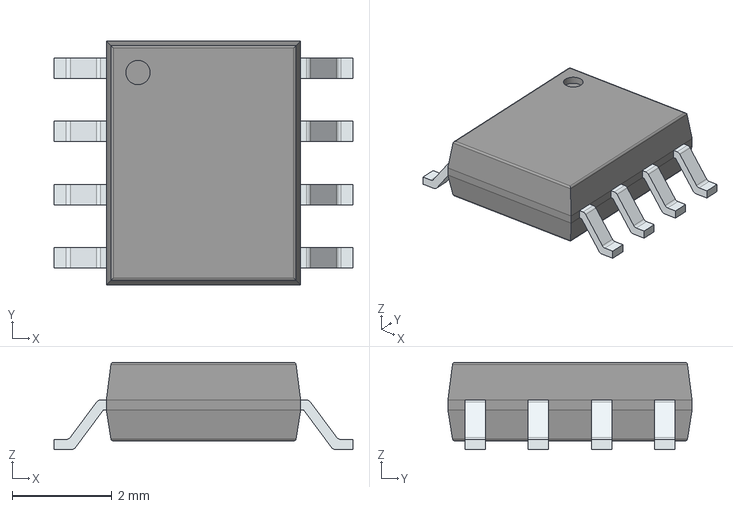
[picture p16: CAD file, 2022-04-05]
pcb/kicad_files/mppt_3d_models/NE555DR.stp
6.00 x 4.90 x 1.75 mm
PinsArrayLR

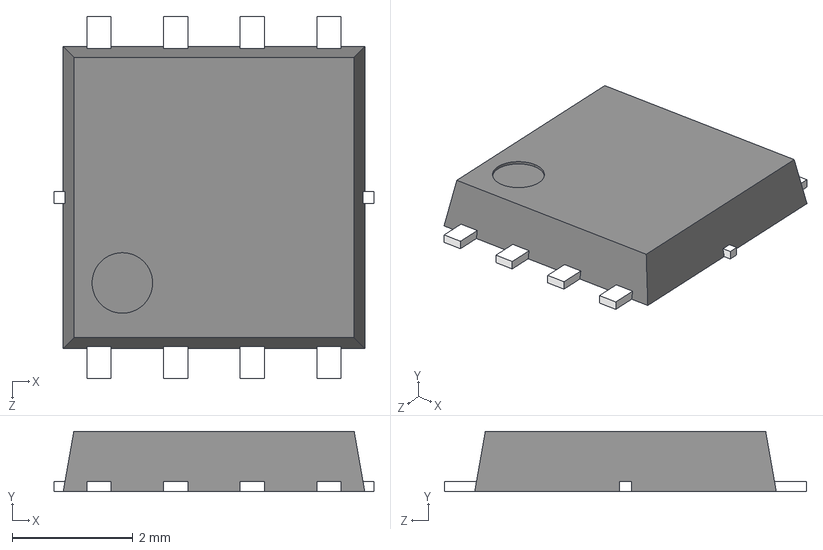
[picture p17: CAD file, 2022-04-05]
pcb/kicad_files/mppt_3d_models/TPH2R608NH,L1Q.STEP
5.30 x 1.00 x 6.00 mm

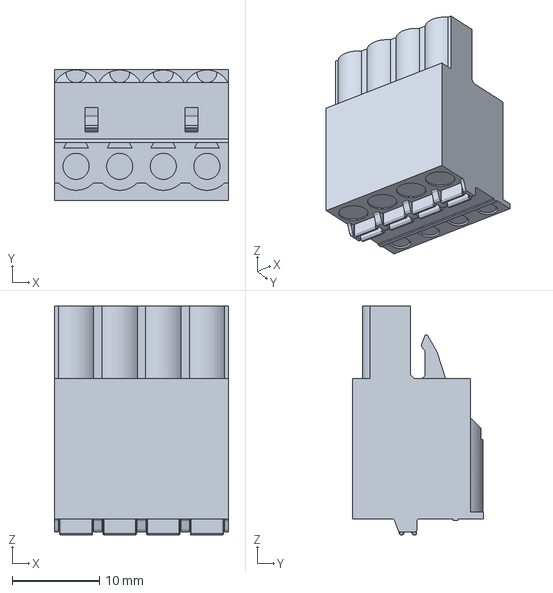
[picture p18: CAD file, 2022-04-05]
pcb/kicad_files/mppt_3d_models/c-2350397-4-1-3d.stp
20.0 x 15.0 x 26.3 mm

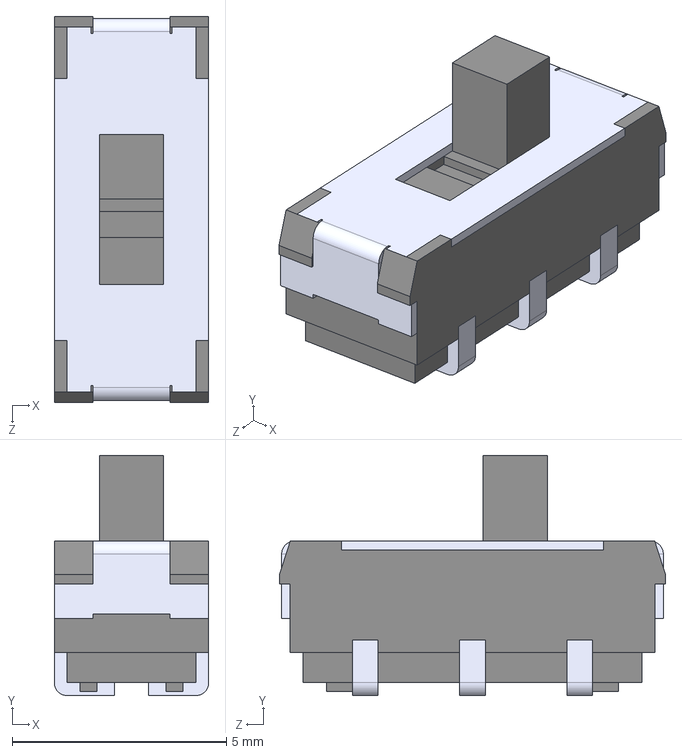
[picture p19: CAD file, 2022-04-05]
pcb/kicad_files/mppt_libraries/Downloads/JS202011JCQN/JS202011JCQN.step
3.60 x 5.60 x 9.00 mm

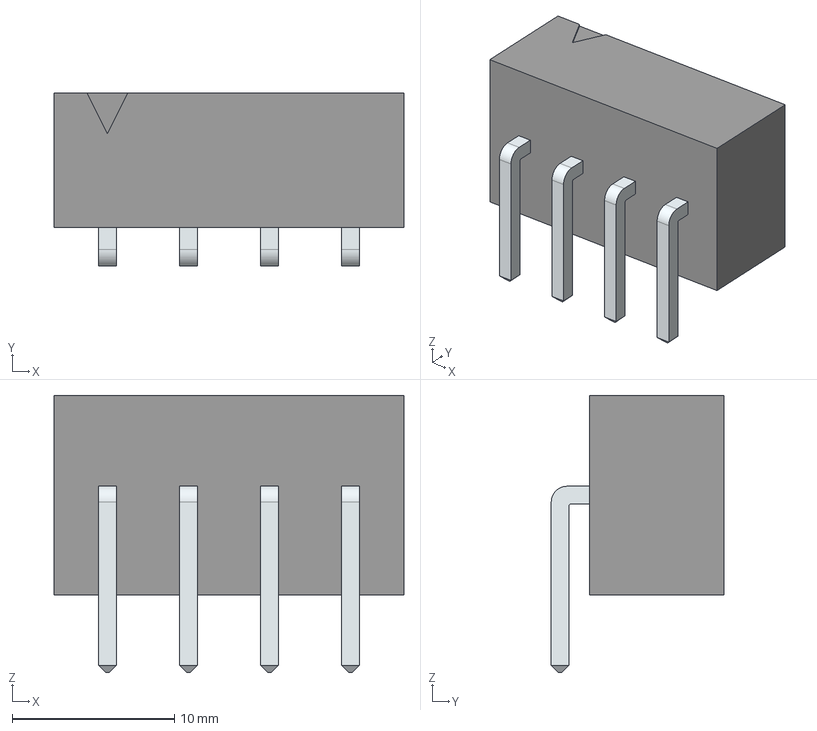
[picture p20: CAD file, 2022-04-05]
pcb/kicad_files/mppt_libraries/Downloads/LIB_2350513-4/2350513-4/3D/2350513-4.stp
21.6 x 10.7 x 17.1 mm
LeadsArray

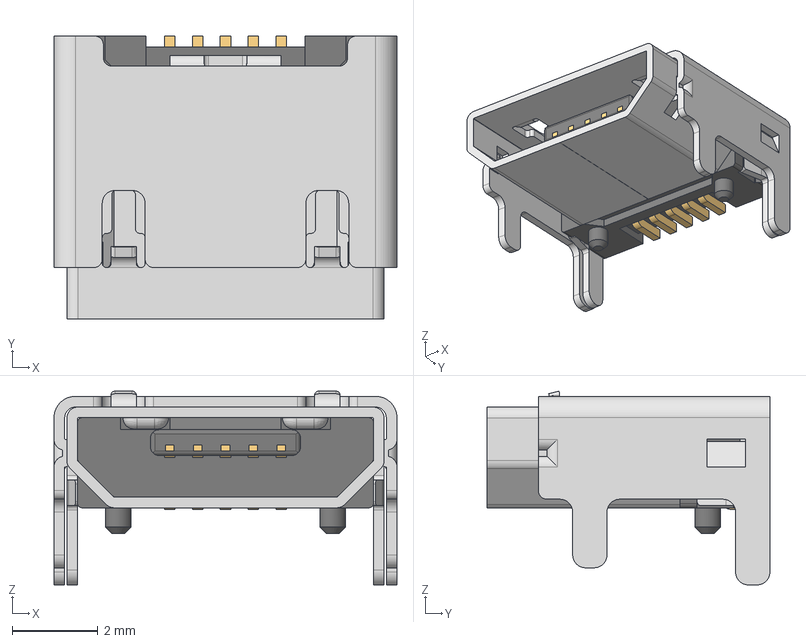
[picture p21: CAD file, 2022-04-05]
pcb/kicad_files/mppt_3d_models/629105150521_Download_STP_629105150521_rev1.stp
8.00 x 6.60 x 4.52 mm
629105150521_Pin1 x 4
629105150521_Housing
629105150521_Pin2
629105150521_Shielding
629105150521_Shielding2

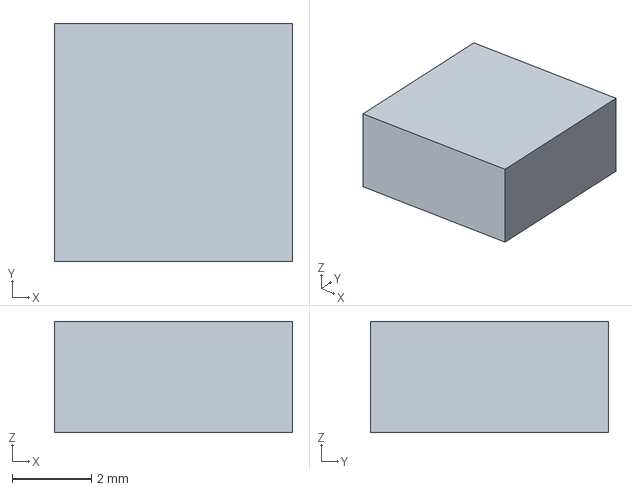
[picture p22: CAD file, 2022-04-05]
pcb/kicad_files/mppt_3d_models/TYS60284R7N Inductor.FCStd
6.00 x 6.00 x 2.80 mm

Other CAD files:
pcb/kicad_files/mppt_3d_models/TYS60284R7N.step
cad/MPPT Rev 2 Case v150.f3z
pcb/kicad_files/mppt_libraries/Downloads/LIB_2350513-4/2350513-4/3D/2350513-4.stl
pcb/kicad_files/mppt_libraries/Downloads/LIB_2350513-4/2350513-4/Allegro/shdrra4w110p0x500_1x4_2160x830x1230p.psm
pcb/kicad_files/mppt_libraries/Downloads/LIB_2350513-4/2350513-4/DEHDL/2350513_4/chips/chips.prt

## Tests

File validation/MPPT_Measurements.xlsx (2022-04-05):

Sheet: Measurements overview
Measured parameter | Additional parameters of interest
Input Step Response
Output ripple at different loads
Output step response | Overshoot, undershoot, recovery time
Safety parameters | Voltage and current limits, battery charge termination voltage
Validate, that the actual MPP is found!

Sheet: Efficiency
Efficiency vs Ouput Power and Input Voltage
 |  |  |  |  |  |  |  | Uin | Avg Efficiency
Efficiency vs Ouput Power at Uin = 16V |  |  |  |  |  |  |  | 16 | 0.921840116
Wirkungsgrad vs Ausgangsleistung bei Uin = 16V |  |  |  |  |  | Average Efficiency | 0.921840116 | 26 | 0.927475258
Uin | Iin | Pin | Uout | Iout | Pout | Efficiency |  | 36 | 0.9185225951
16 | 0.032 | 0.512 | 48 | 0 | 0
16 | 0.50 | 8 | 48.10 | 0.15 | 7.3593 | 0.92
16 | 0.90 | 14.4 | 46.50 | 0.28 | 13.113 | 0.91
16 | 1.50 | 24 | 48.70 | 0.46 | 22.4994 | 0.94
16 | 2.19 | 35.04 | 48.80 | 0.67 | 32.8424 | 0.94
16 | 2.86 | 45.76 | 48.80 | 0.87 | 42.5536 | 0.93
16 | 3.54 | 56.64 | 48.80 | 1.07 | 52.216 | 0.92
16 | 4.30 | 68.8 | 49.00 | 1.30 | 63.504 | 0.92
16 | 4.95 | 79.2 | 48.90 | 1.48 | 72.372 | 0.91
16 | 5.70 | 91.2 | 49.00 | 1.68 | 82.32 | 0.90
16 |  | 0 |  |  | 0 | #DIV/0!
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

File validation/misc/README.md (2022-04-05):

This contains old/outdated stuff that still might be useful.

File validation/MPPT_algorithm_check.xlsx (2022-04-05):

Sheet: Kane MPP Calc and check
Run 1 | 16.04.2021
 |  |  |  |  |  |  |  | Theoretical MPP | Rin=Rout | (static source)
Input resistor | 2.5 | Ohms |  | Output resistor | DC load | Ohms
 |  |  |  |  |  |  |  |  |  |  |  |  |  |  | 62.5
Input |  |  | Power lost on input resistor | Output |  |  | Efficiency |  |  |  | 25 | 0.1 | 24.75 | 2.475 | 62.5 | 0.1 | 28
Voltage | Current | Power |  | Voltage | Current | Power |  |  |  |  | 25 | 0.2 | 24.5 | 4.9 | 62.5 | 0.2 | 28
14 | 2 | 28 | 10 | 15 | 1.45 | 21.75 | 120.83% |  |  |  | 25 | 0.3 | 24.25 | 7.275 | 62.5 | 0.3 | 28
 |  | 0 | 0 |  |  | 0 | #DIV/0! |  |  |  | 25 | 0.4 | 24 | 9.6 | 62.5 | 0.4 | 28
 |  | 0 | 0 |  |  | 0 | #DIV/0! |  |  |  | 25 | 0.5 | 23.75 | 11.875 | 62.5 | 0.5 | 28
 |  | 0 | 0 |  |  | 0 | #DIV/0! |  |  |  | 25 | 0.6 | 23.5 | 14.1 | 62.5 | 0.6 | 28
 |  | 0 | 0 |  |  | 0 | #DIV/0! |  |  |  | 25 | 0.7 | 23.25 | 16.275 | 62.5 | 0.7 | 28
 |  |  |  |  |  |  |  |  |  |  | 25 | 0.8 | 23 | 18.4 | 62.5 | 0.8 | 28
 |  |  |  |  |  |  |  |  |  |  | 25 | 0.9 | 22.75 | 20.475 | 62.5 | 0.9 | 28
 |  |  |  |  |  |  |  |  |  |  | 25 | 1 | 22.5 | 22.5 | 62.5 | 1 | 28
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

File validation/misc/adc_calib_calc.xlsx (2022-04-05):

adc_calc
input | actual input | measured | error (V) | error percentage
5.00 | 4.86 | 4.83 | 0.03 | 0.6172839506%
10.00 | 9.83 | 9.81 | 0.02 | 0.2034587996%
15.00 | 14.83 | 14.78 | 0.05 | 0.3371544167%
20.00 | 19.82 | 19.76 | 0.06 | 0.3027245207%
25.00 | 24.81 | 24.70 | 0.11 | 0.443369609%
30.00 | 29.81 | 29.54 | 0.27 | 0.9057363301%
35.00 | 34.81 | 34.17 | 0.64 | 1.83855214%
adc_calc_2 | WITH ZENER |  |  | voltage injected at the output
input | actual input | measured | error (V) | error percentage | calculated_adc_input_voltage | measured_adc_input_voltage | error percentage
5.00 | 5.00 | 4.97 | 0.03 | 0.60% | 0.2380952381
10.00 | 10.00 | 9.96 | 0.04 | 0.40% | 0.4761904762
15.00 | 15.00 | 14.95 | 0.05 | 0.33% | 0.7142857143
20.00 | 20.00 | 19.93 | 0.07 | 0.35% | 0.9523809524
25.00 | 25.00 | 24.87 | 0.13 | 0.52% | 1.19047619
30.00 | 30.00 | 29.74 | 0.26 | 0.87% | 1.428571429
35.00 | 35.00 | 34.35 | 0.65 | 1.86% | 1.666666667
40.00 | 40.01 | 38.58 | 1.43 | 3.57% | 1.905238095
45.00 | 44.98 | 42.25 | 2.73 | 6.07% | 2.141904762
46.93 | 46.91 | 43.51 | 3.40 | 7.25% | 2.233809524
50.00 | 49.85 | 45.26 | 4.59 | 9.21% | 2.373809524 | 2.165 | 8.80%
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

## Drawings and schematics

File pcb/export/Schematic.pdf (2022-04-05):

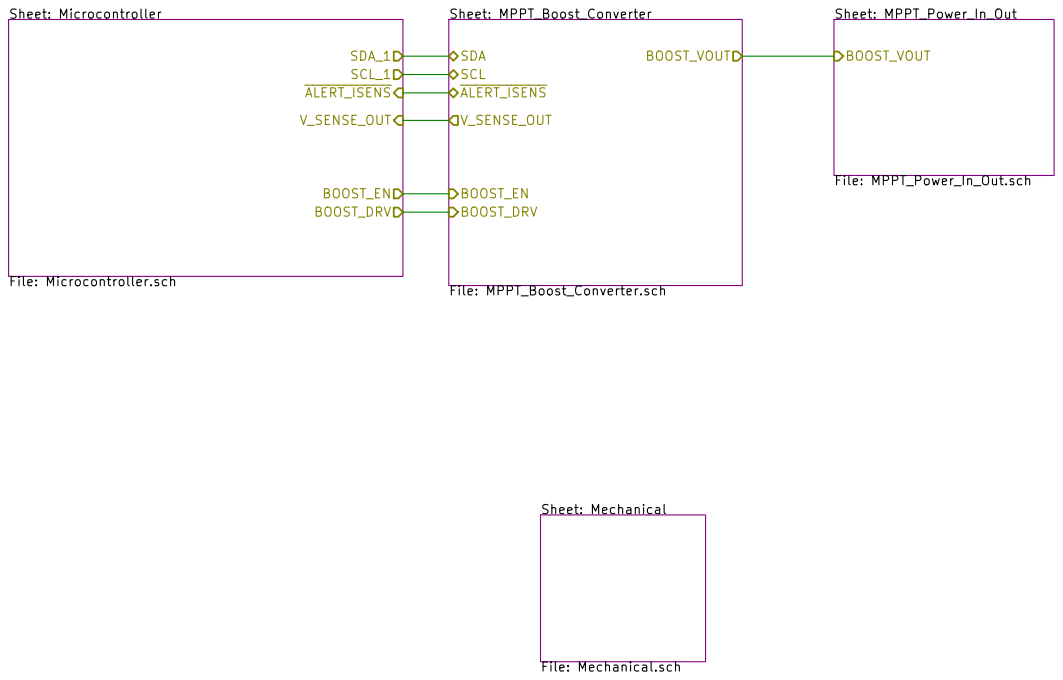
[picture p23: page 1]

BOOST_VOUT Sheet: Mechanical File: Mechanical.sch

File: MPPT_Solar_KiCAD.sch Sheet: / Wilhelm Zeuschner MPPT Solarboot Team HS Emden

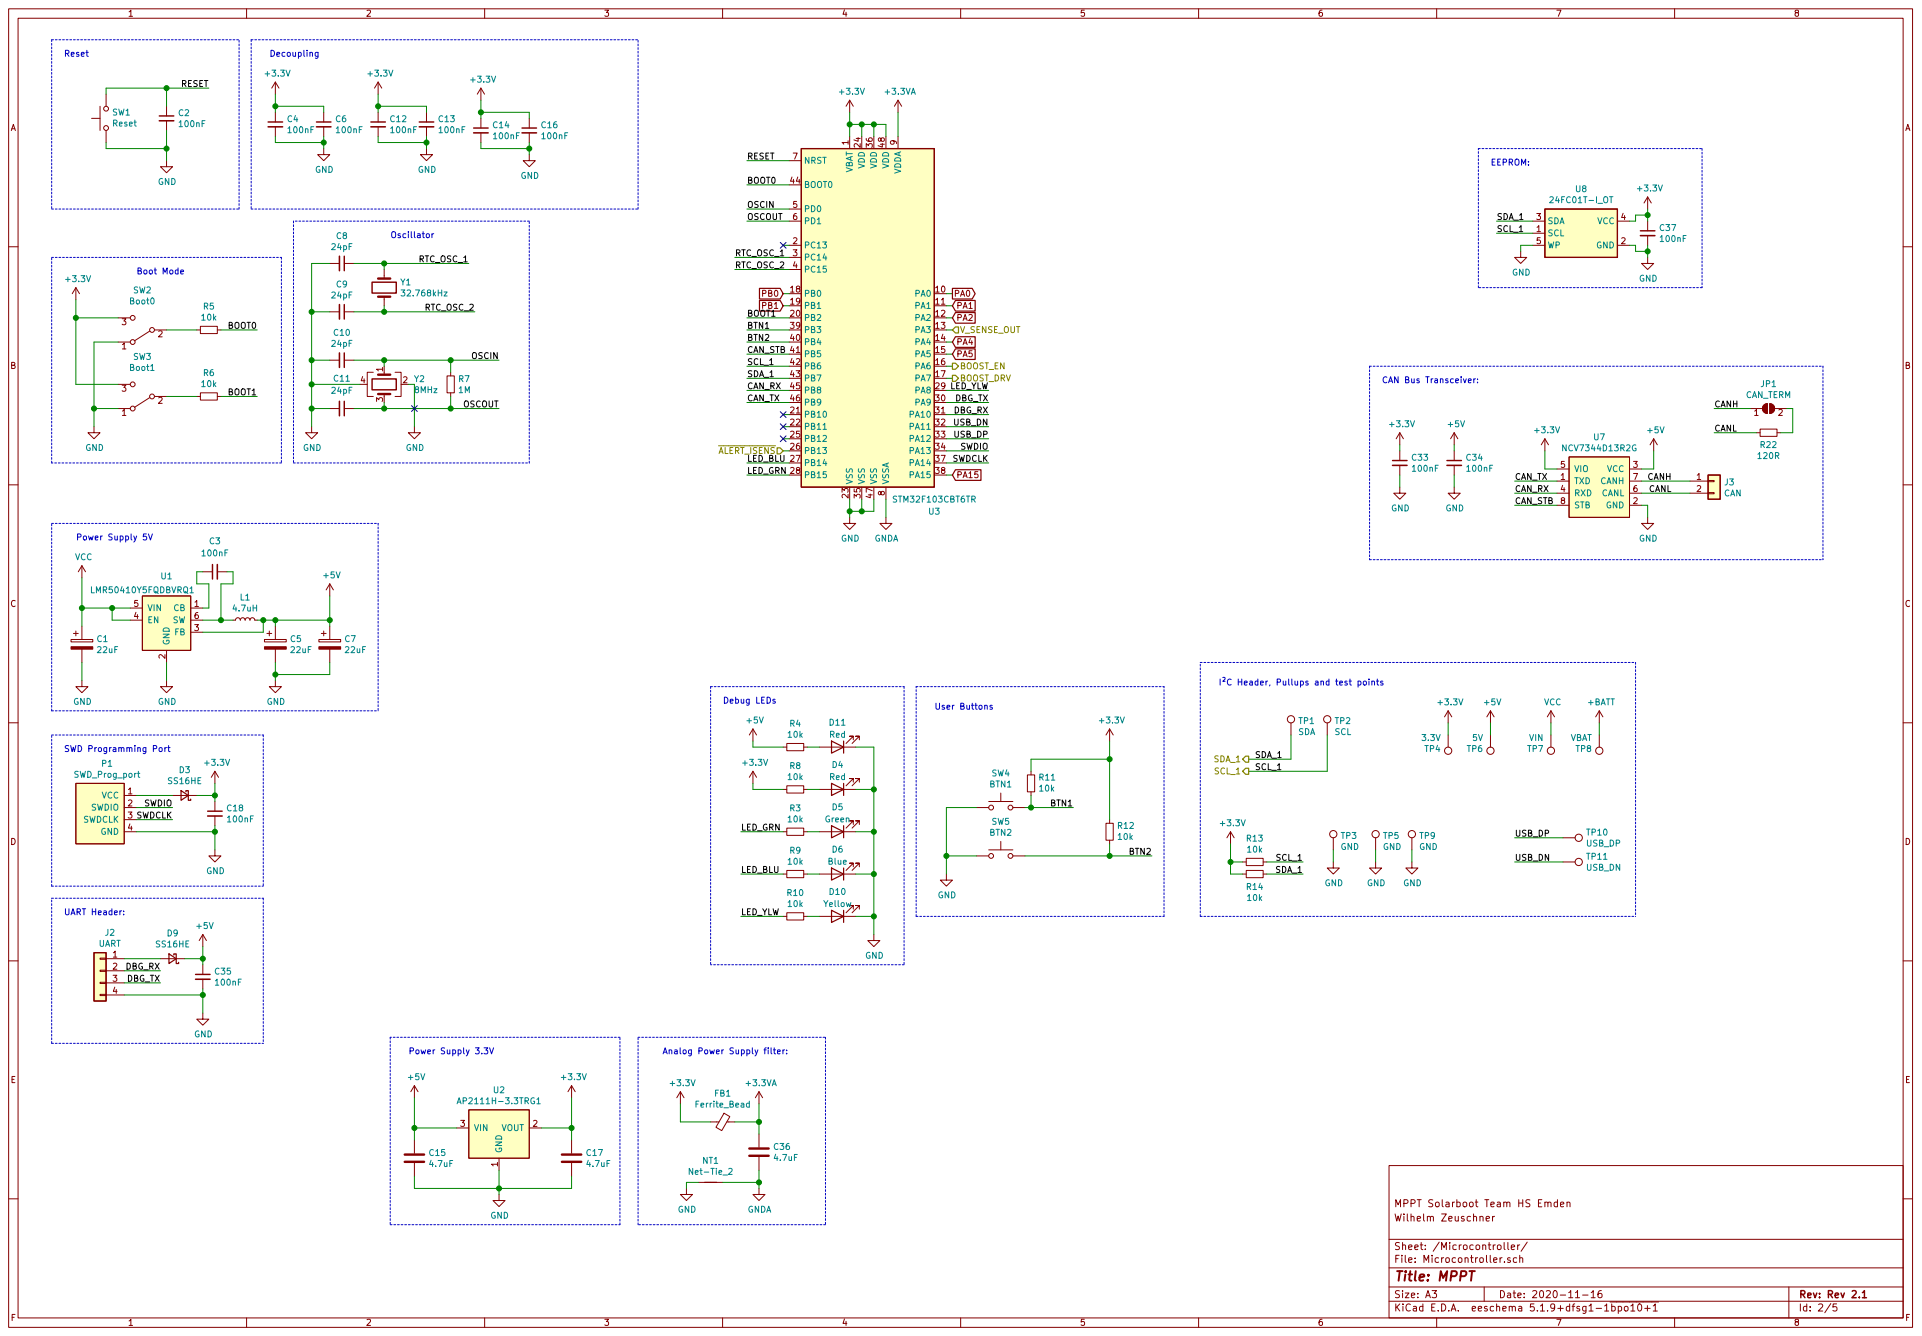
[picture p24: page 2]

1 VDD 24 VDD 36 VDD 48 VDDA

9 VSS 23 VSS 35 VSS 47 VSSA

2 FB 3 EN 4 VIN 5 SW 6 U1

I²C Header, Pullups and test points

File: Microcontroller.sch Sheet: /Microcontroller/ Wilhelm Zeuschner MPPT Solarboot Team HS Emden R13

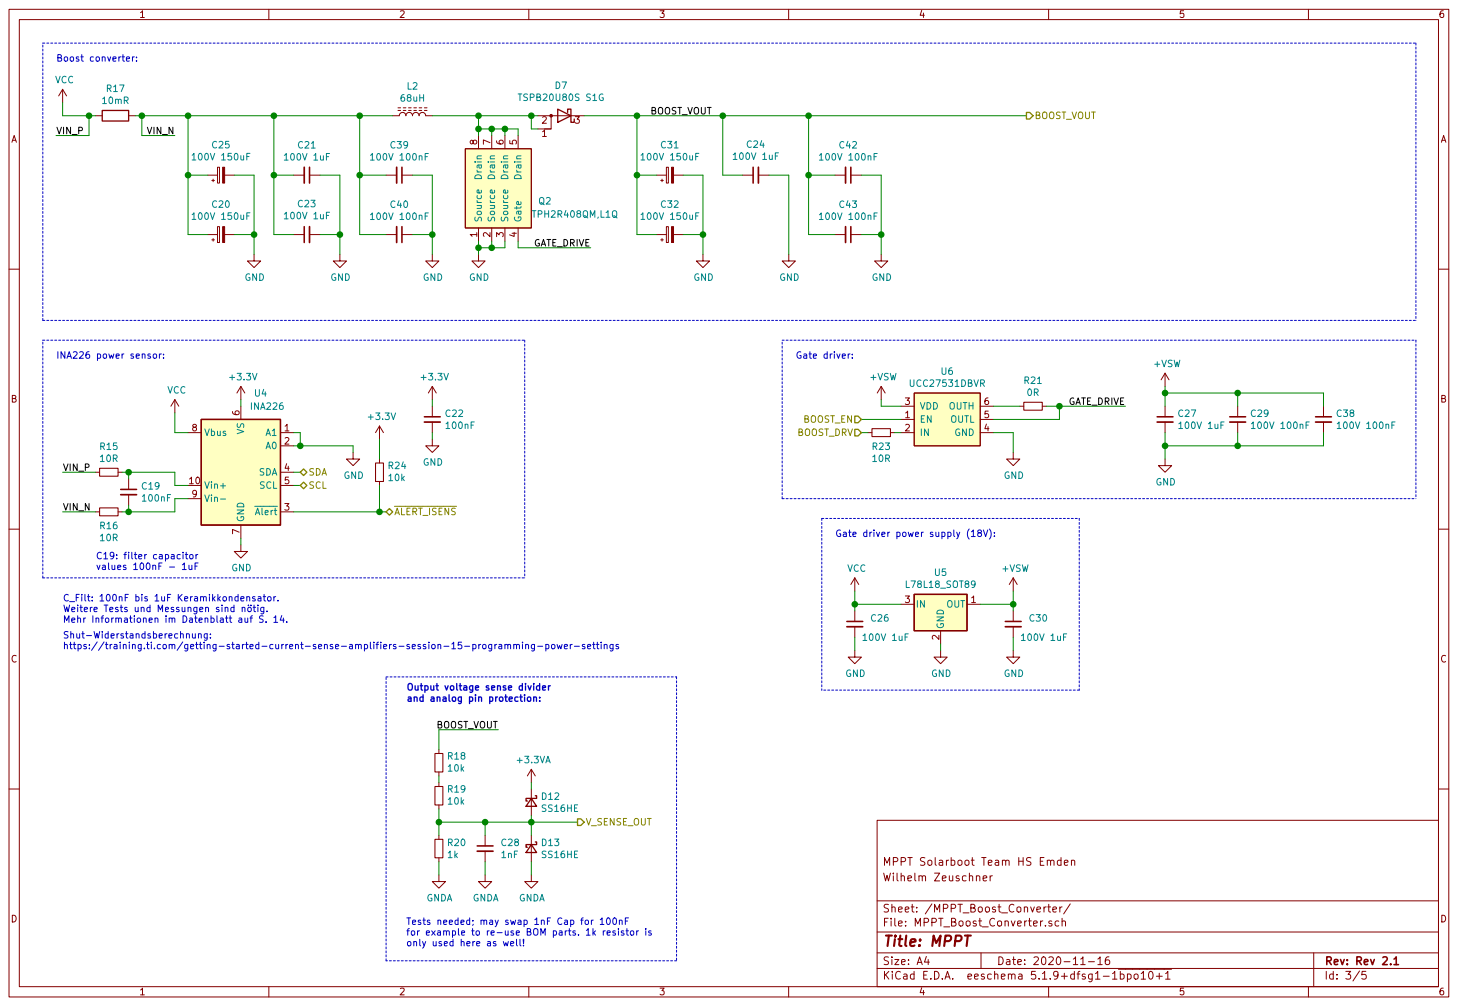
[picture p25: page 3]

Shut-Widerstandsberechnung:
https://training.ti.com/getting-started-current-sense-amplifiers-session-15-programming-power-settings

Sheet: /MPPT_Boost_Converter/ Wilhelm Zeuschner MPPT Solarboot Team HS Emden

Tests needed; may swap 1nF Cap for 100nF
for example to re-use BOM parts. 1k resistor is
only used here as well!

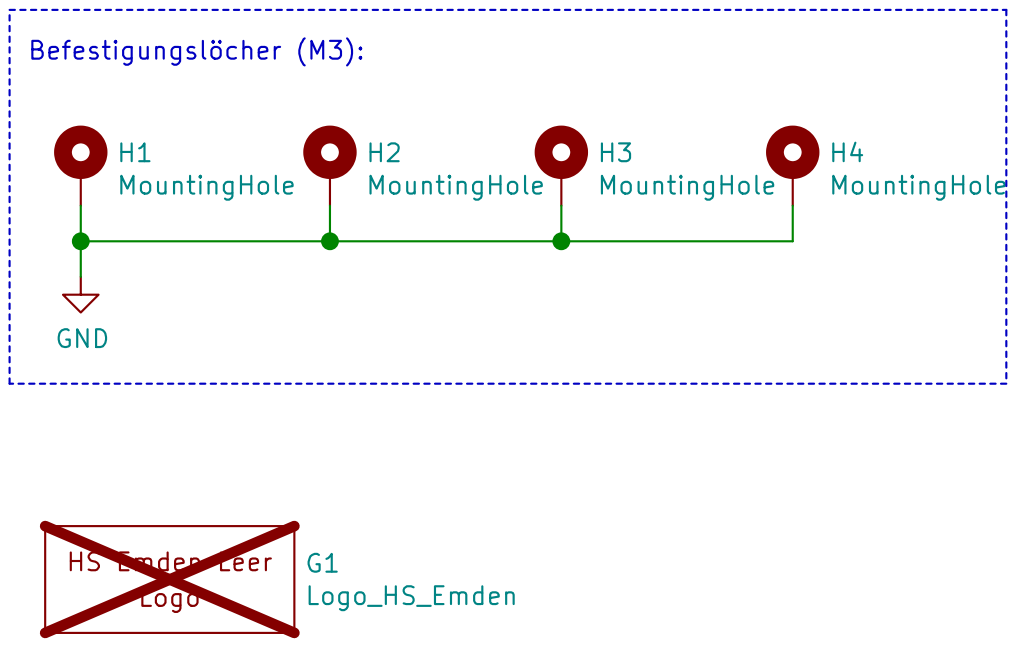
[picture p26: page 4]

File: Mechanical.sch Sheet: /Mechanical/ Wilhelm Zeuschner

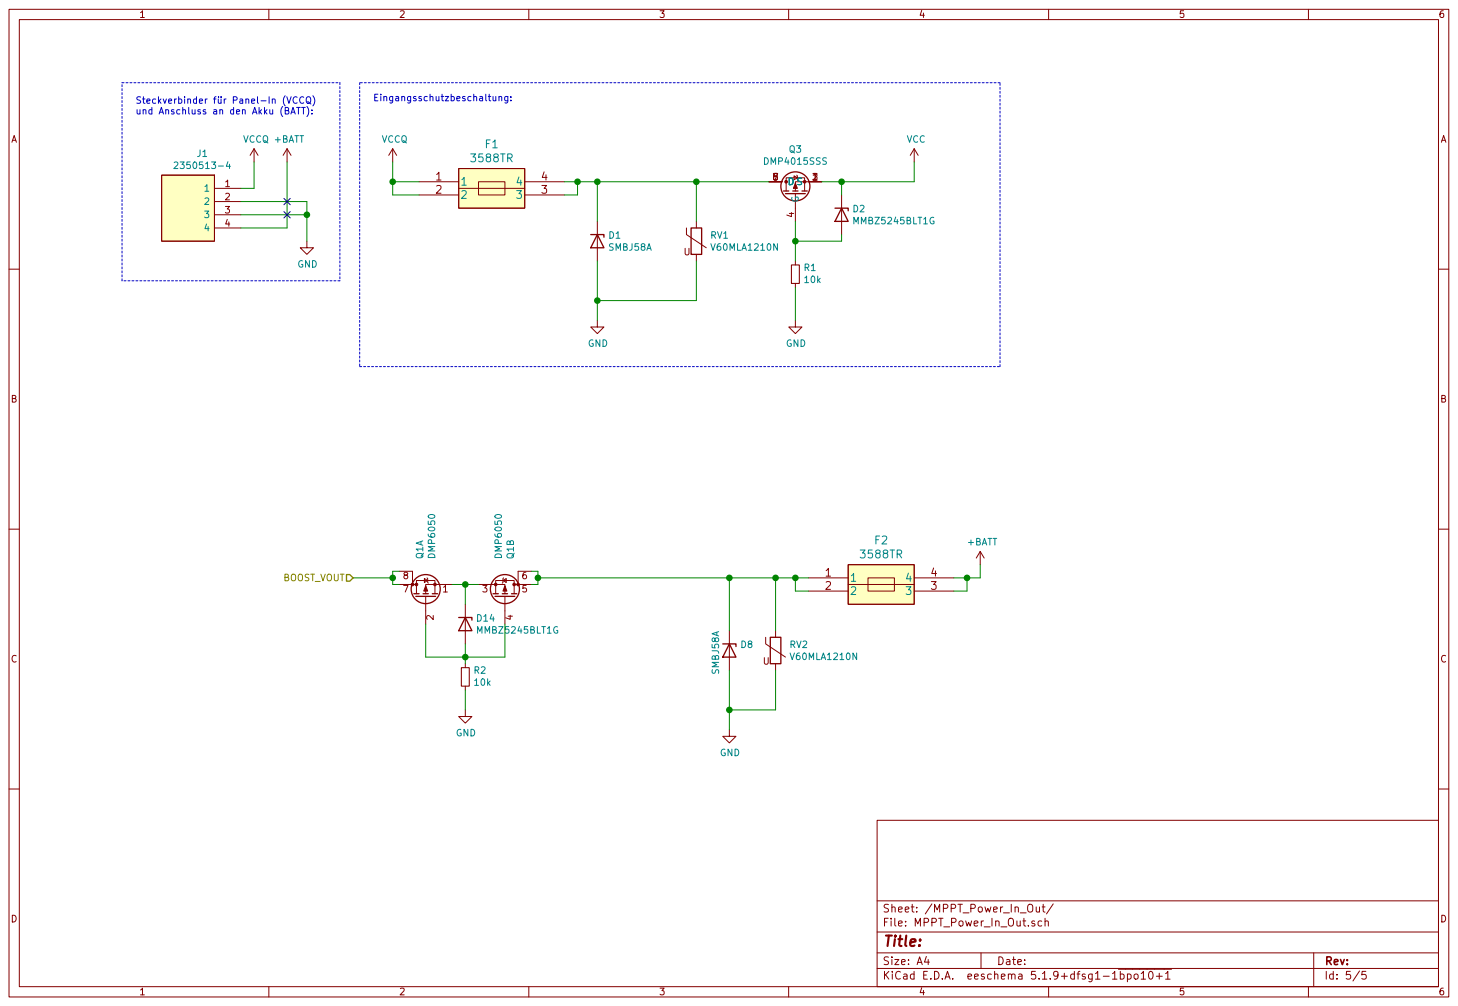
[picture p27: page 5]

und Anschluss an den Akku (BATT):

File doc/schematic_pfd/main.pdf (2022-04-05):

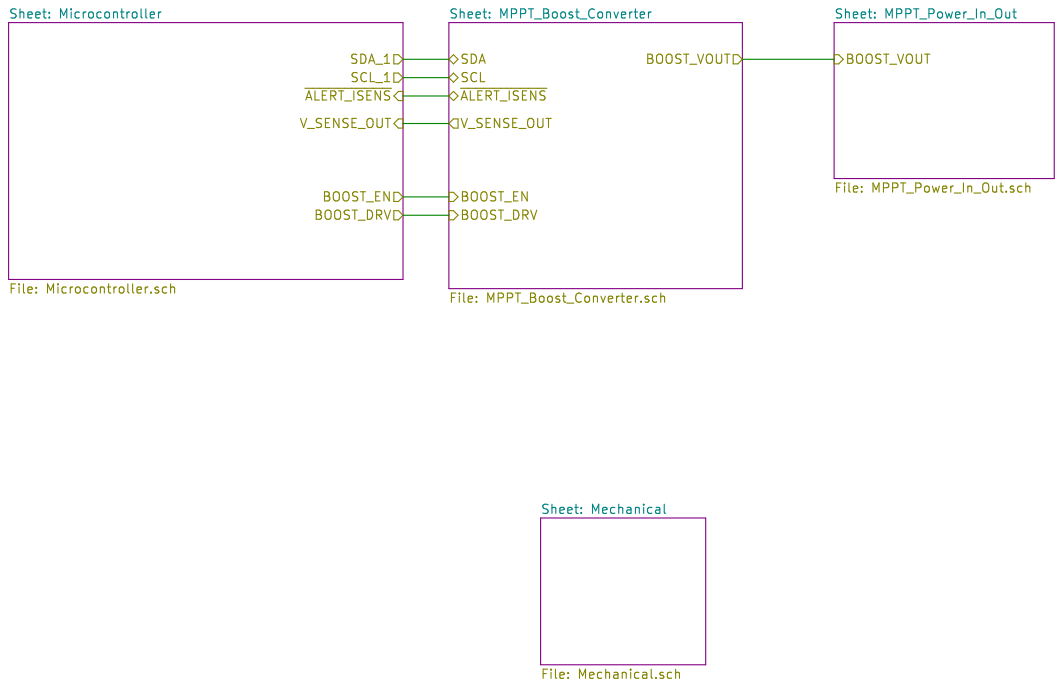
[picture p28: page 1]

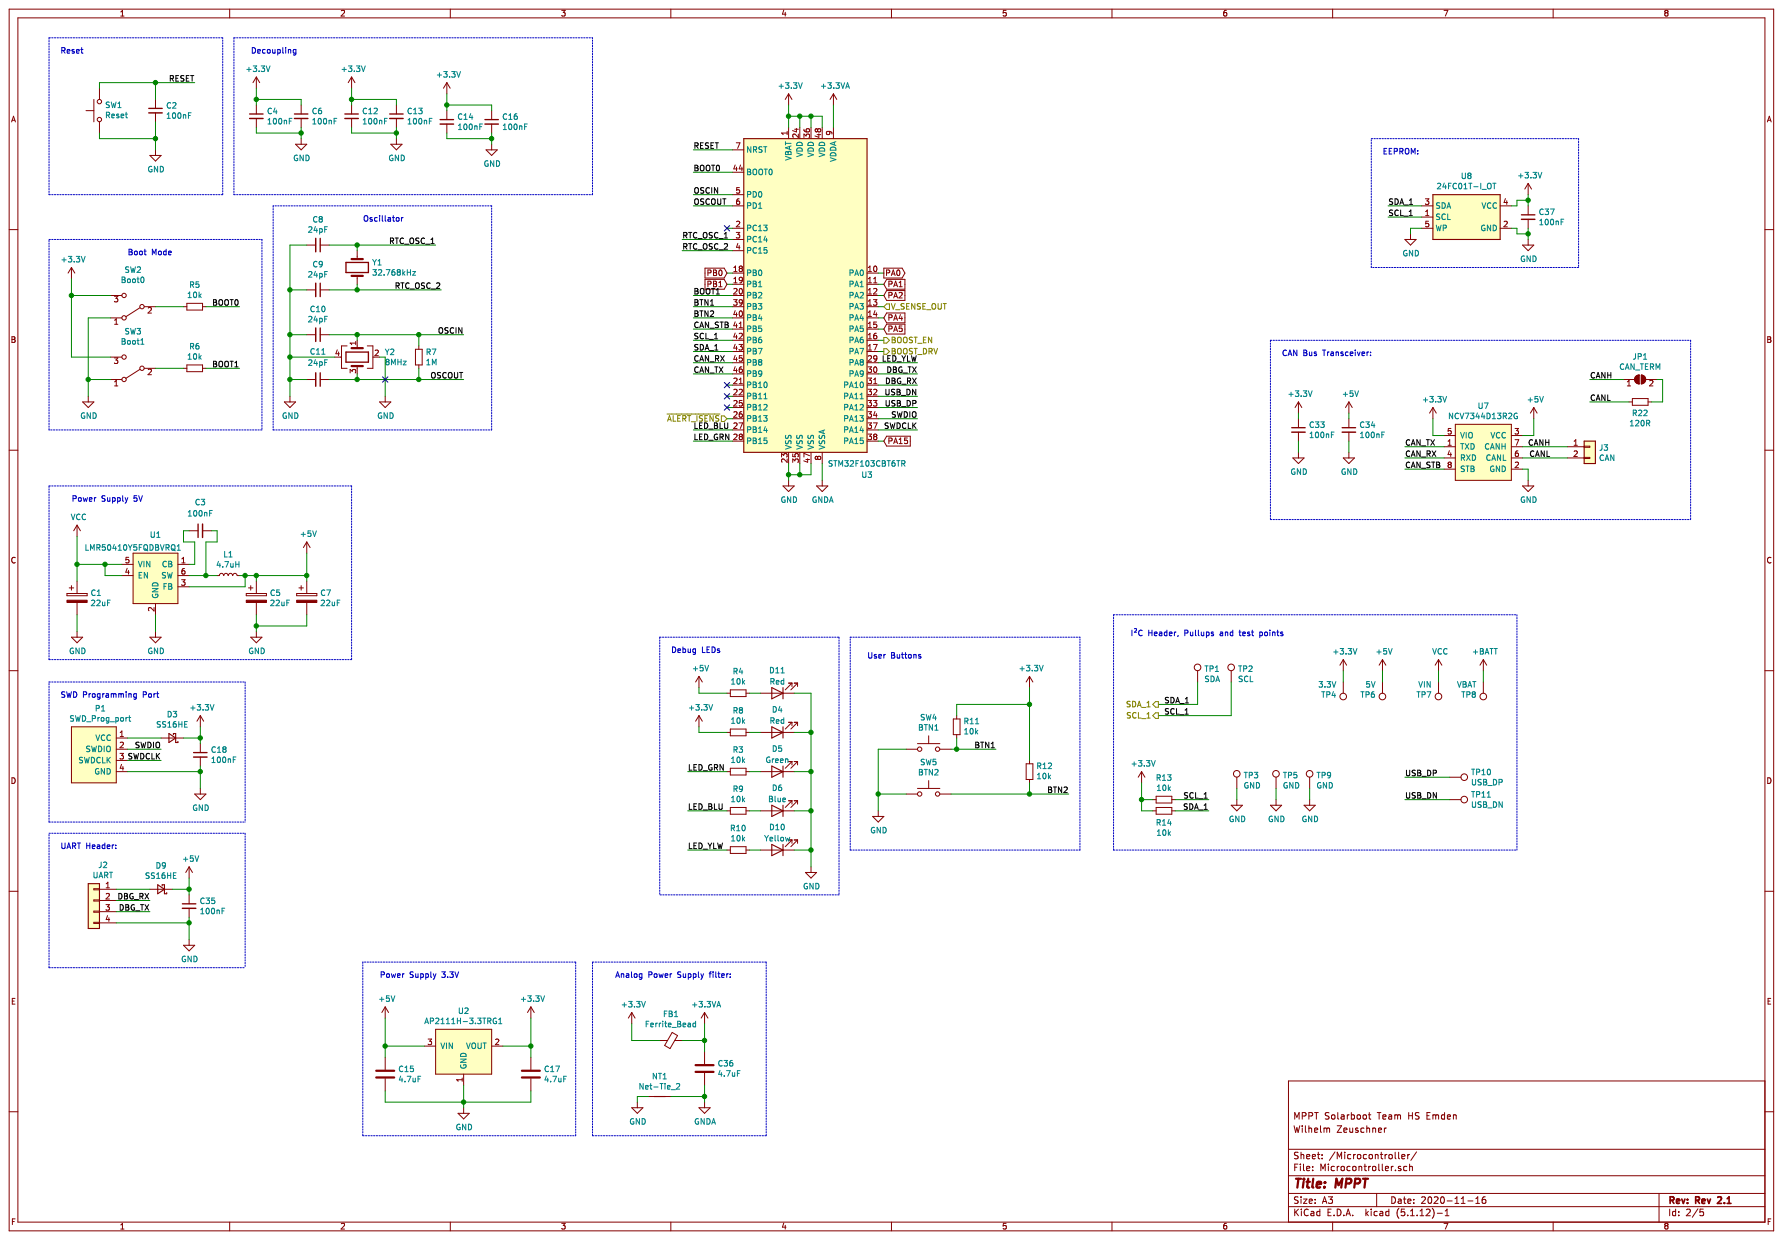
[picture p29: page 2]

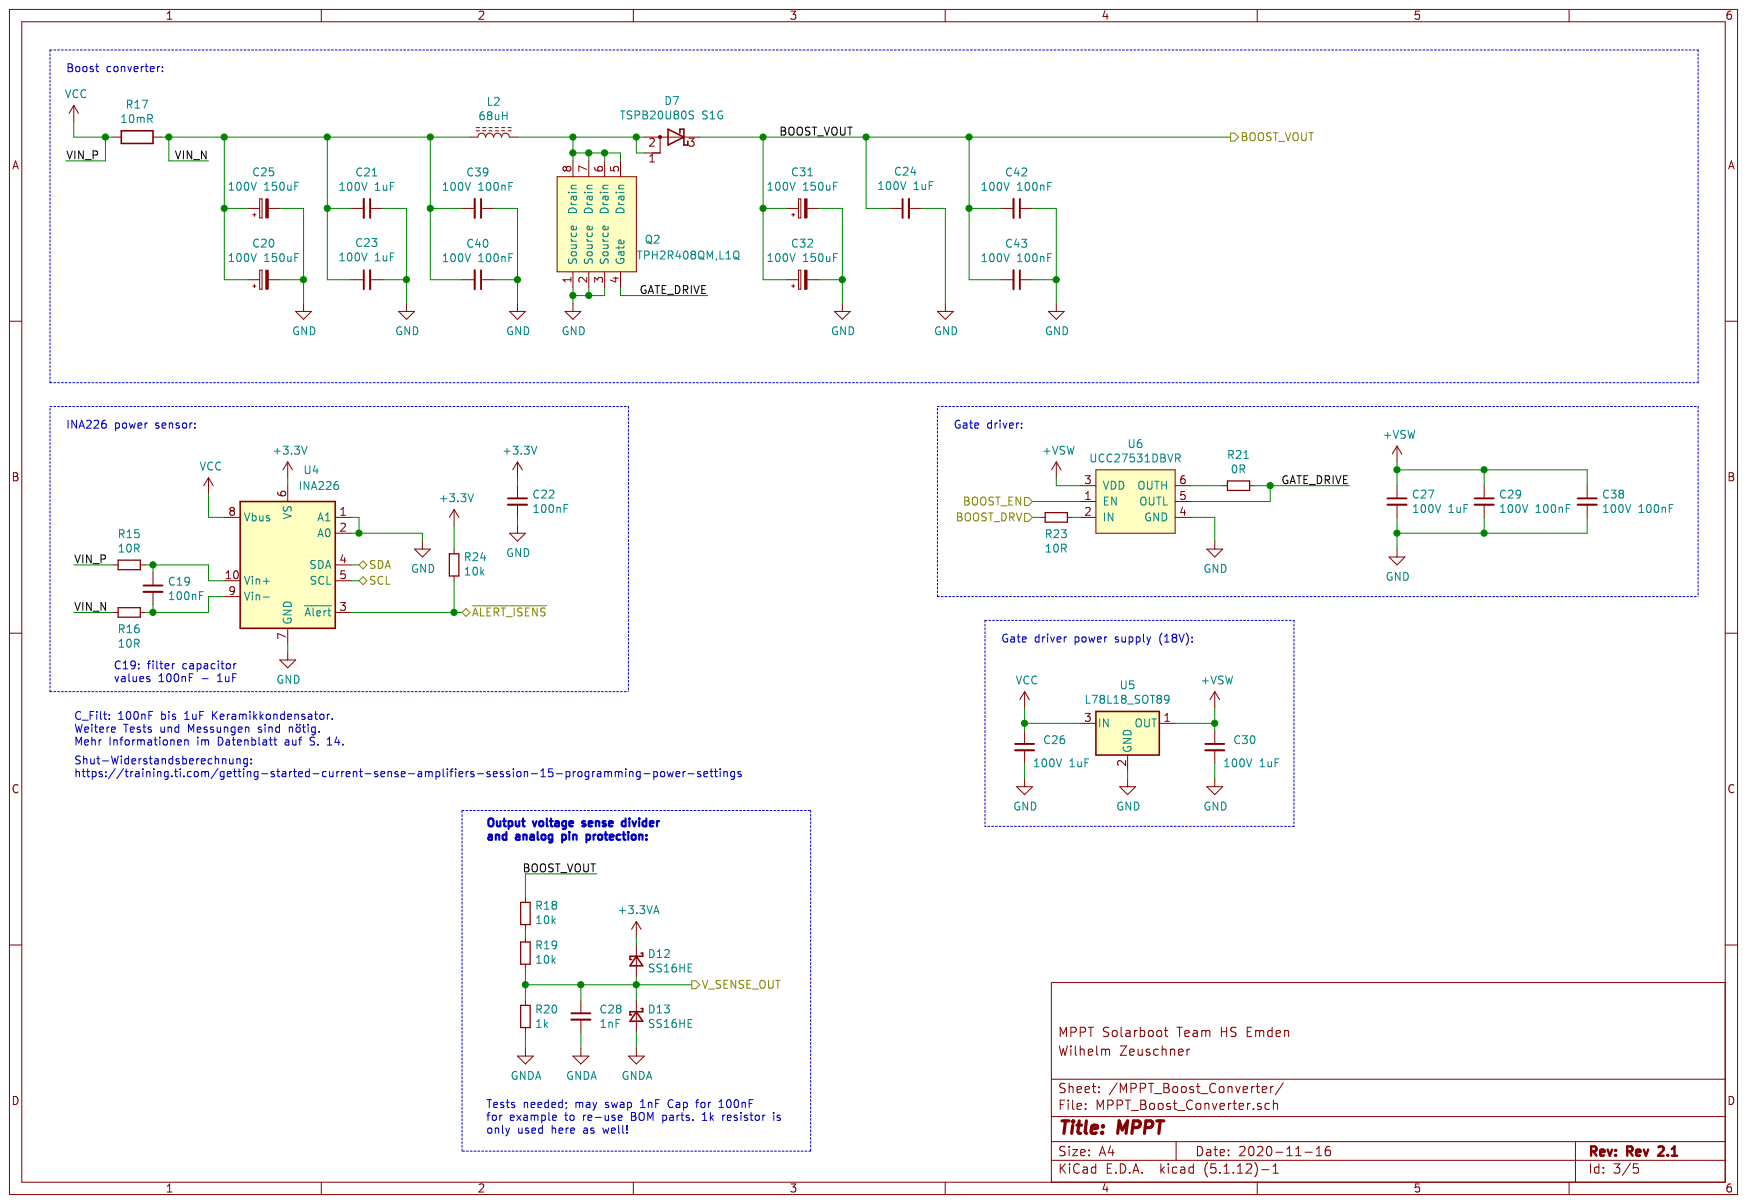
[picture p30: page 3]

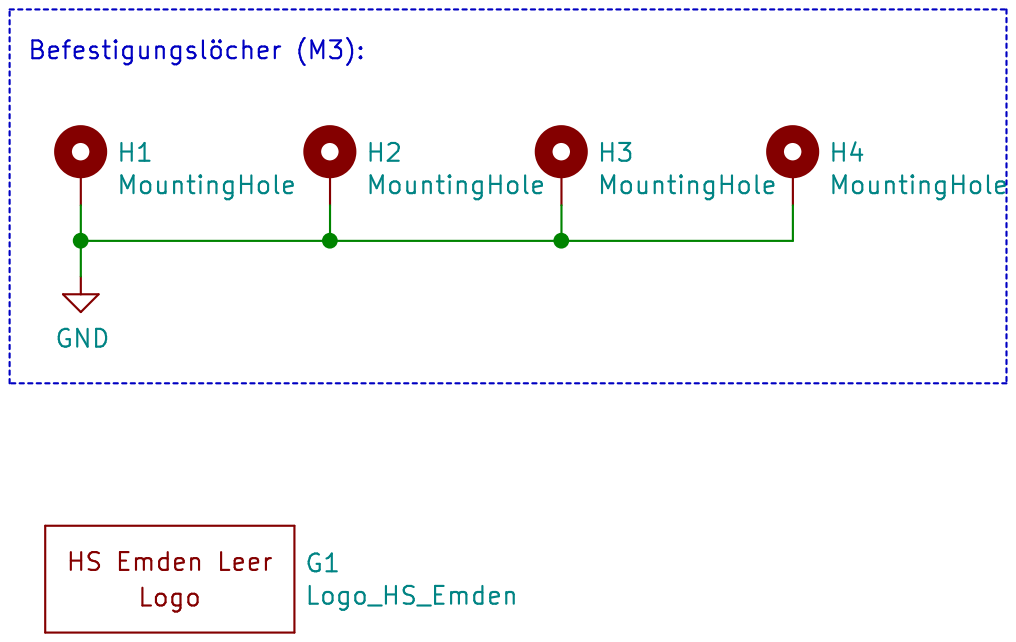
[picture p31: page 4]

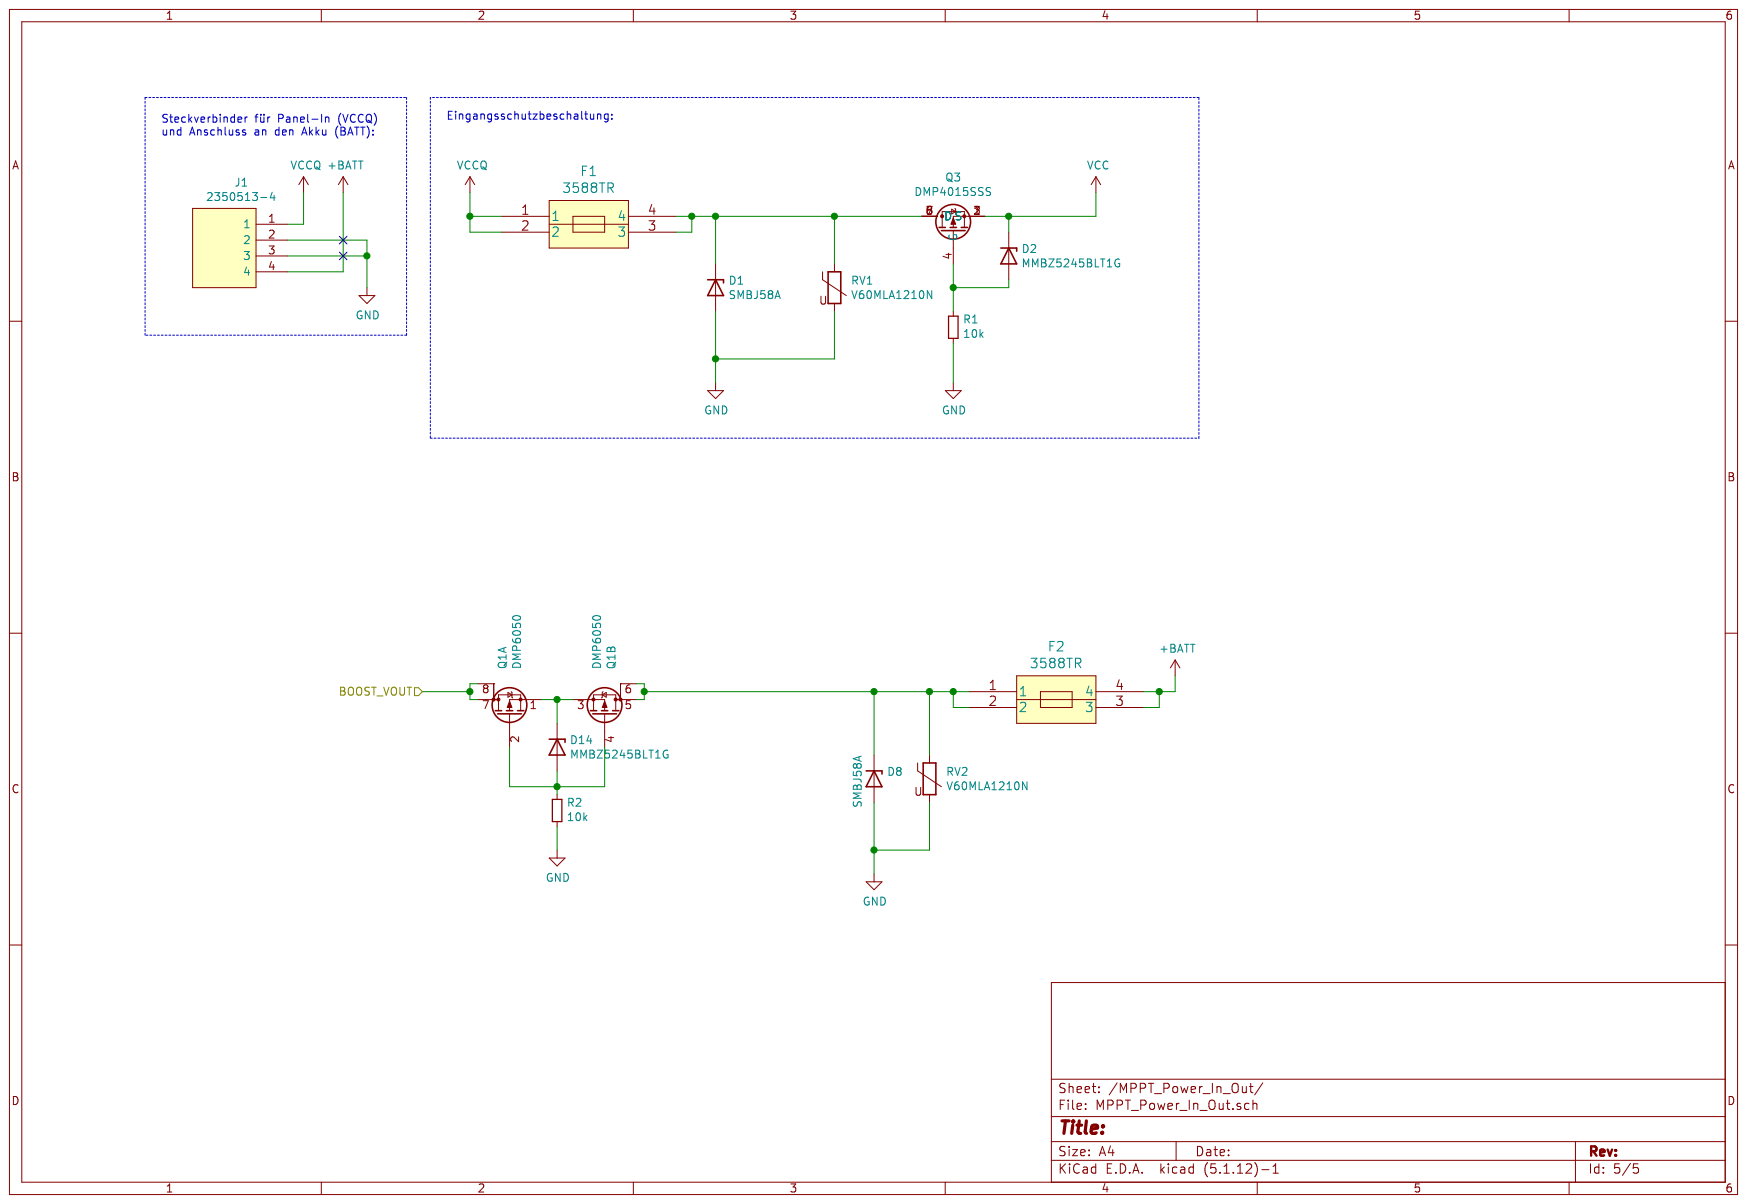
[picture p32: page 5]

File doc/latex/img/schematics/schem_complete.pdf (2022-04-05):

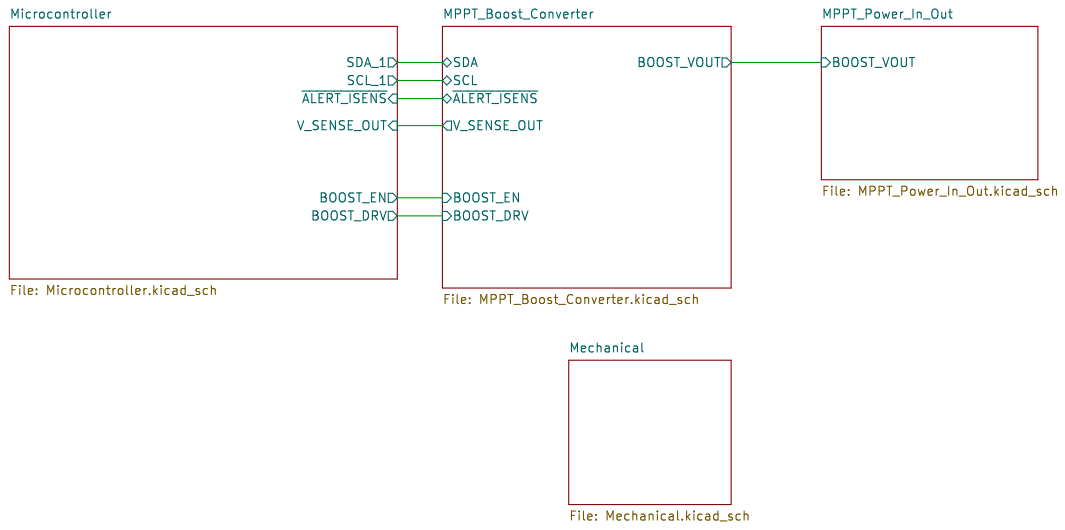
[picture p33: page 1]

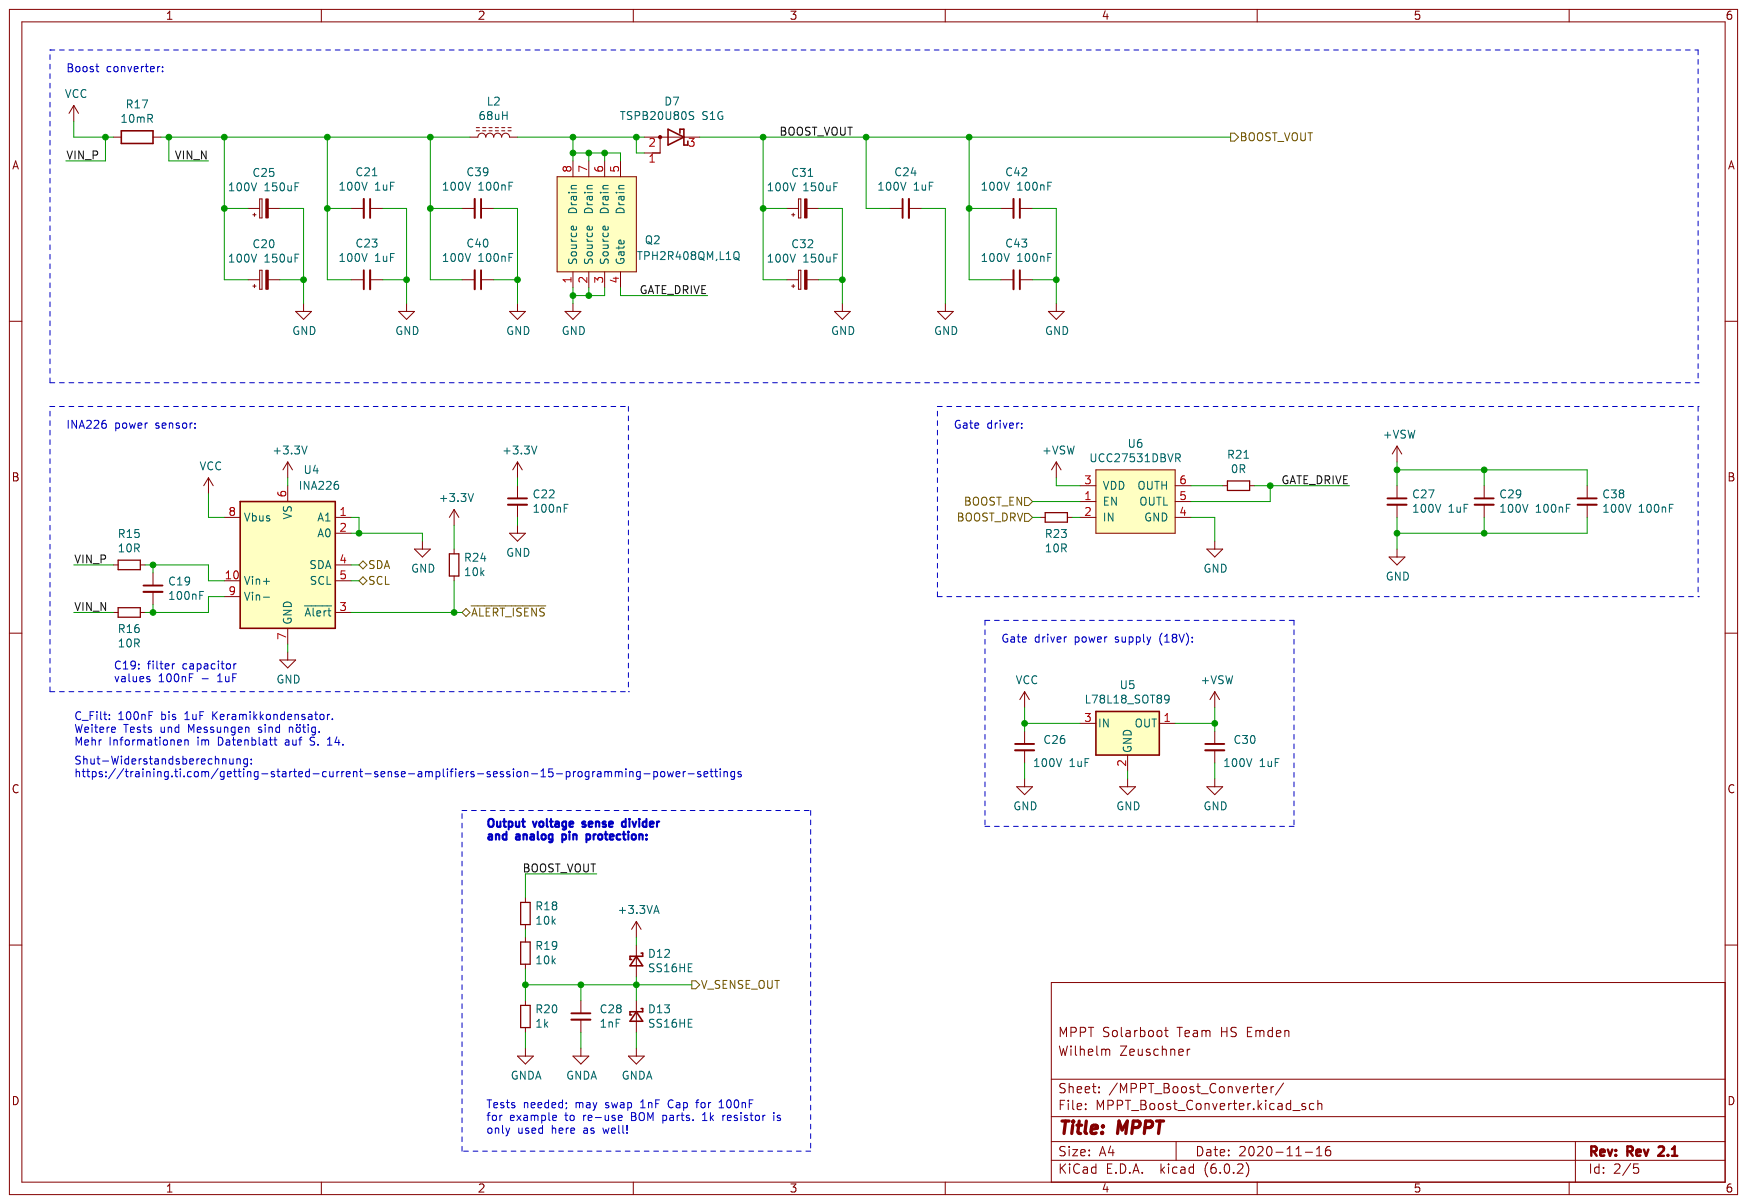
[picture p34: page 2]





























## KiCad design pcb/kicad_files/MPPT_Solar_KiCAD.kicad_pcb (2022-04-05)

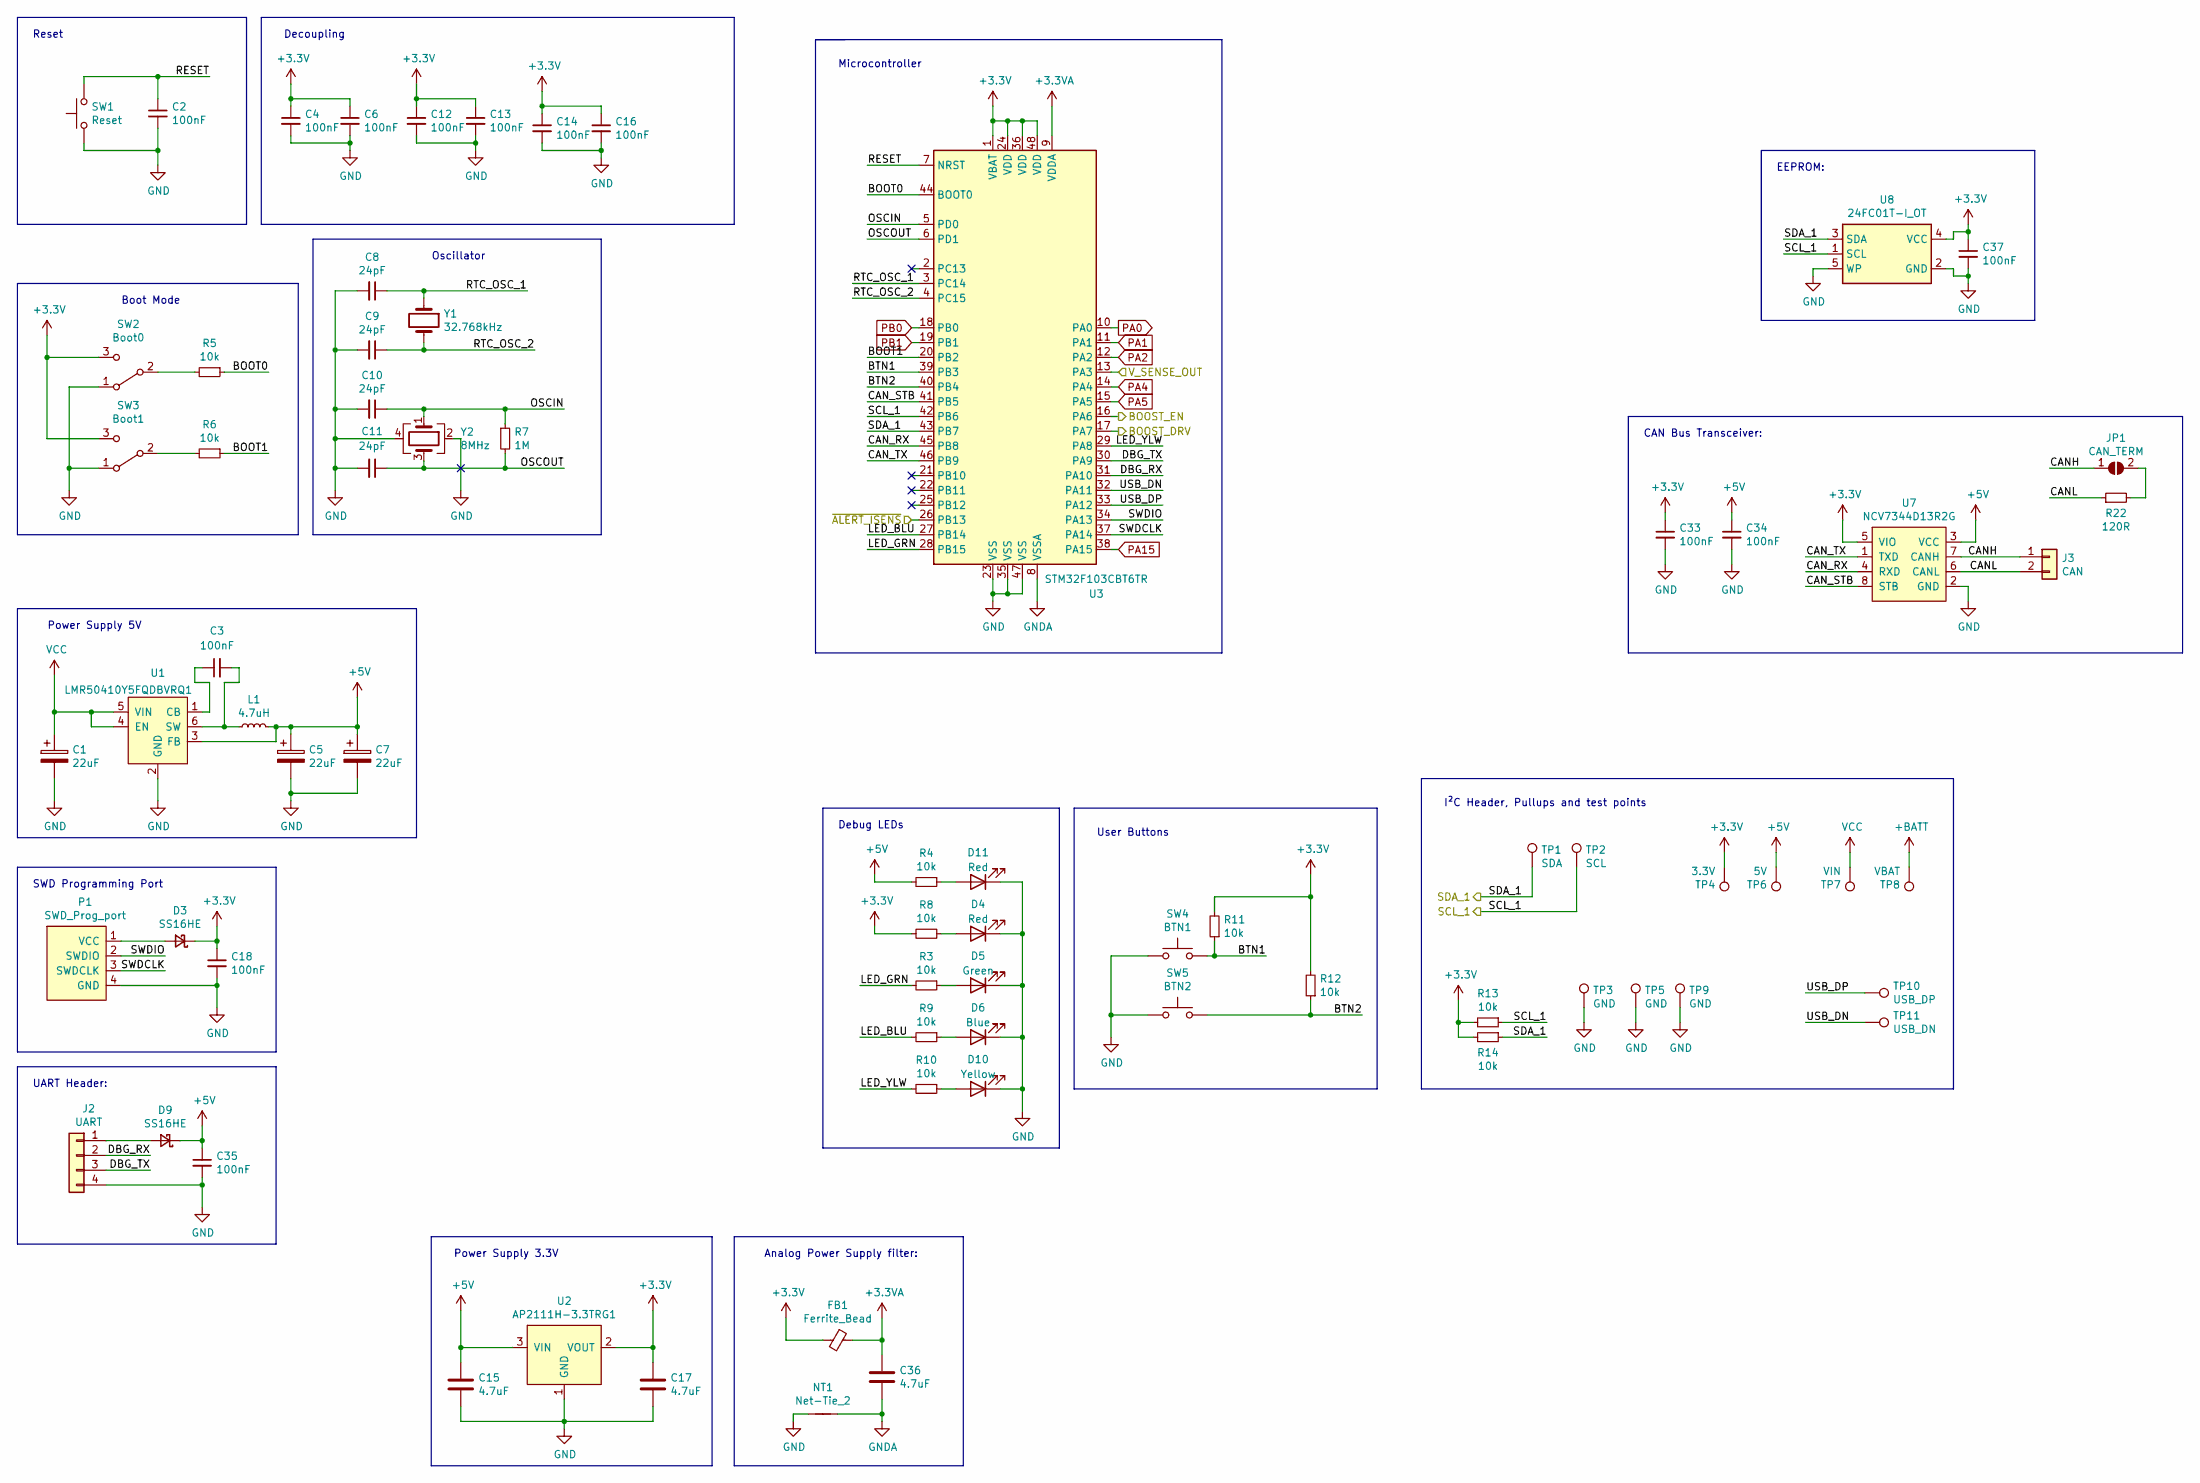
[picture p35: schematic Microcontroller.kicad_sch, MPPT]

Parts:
C1, C5, C7: 22uF; CP_Elec_5x5.9; Manufacturer Part Number 865080643008; Digikey Part No PCE5022CT-ND
C2, C3, C4, C6, C12, C13, C14, C16, C18, C33, C34, C35, C37: 100nF; C_0603_1608Metric; Manufacturer Part Number LMK063C6104KP-F; Digikey Part No 1276-CL10B104KB8NNNLCT-ND
C8, C9, C10, C11: 24pF; C_0603_1608Metric; Manufacturer Part Number 80-C0603C240G1HACTU; Digikey Part No 1276-1761-1-ND
C15, C17, C36: 4.7uF; C_0805_2012Metric; Manufacturer Part Number 885012107013; Digikey Part No 1276-1244-1-ND
D3, D9: SS16HE; D_SOD-323; Manufacturer Part Number SS16HE; Digikey Part No SS16HECT-ND
D4, D11: Red; LED_0805_2012Metric; Manufacturer Part Number 150080RS75000; Digikey Part No 732-4984-1-ND
D5: Green; LED_0805_2012Metric; Manufacturer Part Number 150080GS75000; Digikey Part No 732-4983-1-ND
D6: Blue; LED_0805_2012Metric; Manufacturer Part Number 150080BS75000; Digikey Part No 732-4982-1-ND
D10: Yellow; LED_0805_2012Metric; Manufacturer Part Number 150080YS75000; Digikey Part No 732-4987-1-ND
FB1: Ferrite_Bead; L_0603_1608Metric; Manufacturer Part Number BLM18TG102TN1D; Digikey Part No 490-9701-1-ND
J2: UART; PinHeader_1x04_P2.54mm_Vertical; Manufacturer Part Number RS1-04-G; Digikey Part No 2057-RS1-04-G-ND
J3: CAN; 1713017; Manufacturer Part Number 1713017; Digikey Part No 277-8591-ND
JP1: CAN_TERM; SolderJumper-2_P1.3mm_Open_RoundedPad1.0x1.5mm
L1: 4.7uH; 60x60mm_Inductor; Manufacturer Part Number NRS6028T4R7MMGK; Digikey Part No 587-2943-1-ND
NT1: Net-Tie_2; NetTie-2_SMD_Pad0.5mm
P1: SWD_Prog_port; PinSocket_1x04_P2.54mm_Vertical; Manufacturer Part Number RS1-04-G; Digikey Part No 2057-RS1-04-G-ND
R3, R4, R5, R6, R8, R9, R10, R11, R12, R13, R14: 10k; R_0603_1608Metric; Manufacturer Part Number RC0603FR-0710KL; Digikey Part No 311-10.0KHRCT-ND
R7: 1M; R_0603_1608Metric; Manufacturer Part Number RC0603FR-071ML; Digikey Part No 311-1.00MHRCT-ND
R22: 120R; R_1206_3216Metric; Manufacturer Part Number RC1206FR-07120RL; Digikey Part No 311-120FRCT-ND
SW1: Reset; SW_SPST_EVQPE1; Manufacturer Part Number CKN12317-1-ND; Digikey Part No CKN12317-1-ND
SW2: Boot0; SW_JS202011JCQN; Manufacturer Part Number JS202011JCQN; Digikey Part No CKN10723CT-ND
SW3: Boot1; SW_JS202011JCQN; Manufacturer Part Number JS202011JCQN; Digikey Part No CKN10723CT-ND
SW4: BTN1; SW_SPST_EVQPE1; Manufacturer Part Number CKN12317-1-ND; Digikey Part No CKN12317-1-ND
SW5: BTN2; SW_SPST_EVQPE1; Manufacturer Part Number CKN12317-1-ND; Digikey Part No CKN12317-1-ND
TP1: SDA; TestPoint_Pad_D1.0mm
TP2: SCL; TestPoint_Pad_D1.0mm
TP3, TP5, TP9: GND; TestPoint_Pad_D1.0mm
TP4: 3.3V; TestPoint_Pad_D1.0mm
TP6: 5V; TestPoint_Pad_D1.0mm
TP7: VIN; TestPoint_Pad_D1.0mm
TP8: VBAT; TestPoint_Pad_D1.0mm
TP10: USB_DP; TestPoint_Pad_D1.0mm
TP11: USB_DN; TestPoint_Pad_D1.0mm
U1: LMR50410Y5FQDBVRQ1; SOT-23-6; Manufacturer Part Number LMR50410Y5FQDBVRQ1; Digikey Part No 296-LMR50410Y5FQDBVRQ1CT-ND
U2: AP2111H-3.3TRG1; SOT-223-3_TabPin2; Manufacturer Part Number AP2111H-3.3TRG1; Digikey Part No AP2111H-3.3TRG1DICT-ND
U3: STM32F103CBT6TR; LQFP-48_7x7mm_P0.5mm; Manufacturer Part Number STM32F103CBT6TR; Digikey Part No 497-17380-1-ND
U7: NCV7344D13R2G; SOIC-8_3.9x4.9mm_P1.27mm; Manufacturer Part Number NCV7344D13R2G; Digikey Part No NCV7344D13R2GOSCT-ND
U8: 24FC01T-I_OT; SOT-23-5; Manufacturer Part Number 24FC01T-I/OT; Digikey Part No 24FC01T-I/OTCT-ND
Y1: 32.768kHz; Crystal_SMD_MicroCrystal_CC7V-T1A-2Pin_3.2x1.5mm; Manufacturer Part Number FC-135R 32.7680KF-A3; Digikey Part No SER4076CT-ND
Y2: 8MHz; Crystal_SMD_3225-4Pin_3.2x2.5mm; Manufacturer Part Number ECS-80-12-33Q-GN-TR; Digikey Part No 50-ECS-80-12-33Q-GN-CT-ND

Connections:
+3.3VA: C36.1, FB1.1, U3.9 (VDDA); also elsewhere on the board
+3V3: C4.1, C6.1, C12.1, C13.1, C14.1, C16.1, C17.1, C18.1, C33.1, C37.1, D3.1 (K), FB1.2, R8.2, R11.2, R12.2, R13.2, R14.2, SW2.3 (C), SW3.3 (C), TP4.1, U2.2 (VOUT), U2.4 (VOUT), U3.1 (VBAT), U3.24 (VDD), U3.36 (VDD), U3.48 (VDD), U7.5 (VIO), U8.4 (VCC); also elsewhere on the board
+5V: C5.1, C7.1, C15.1, C34.1, C35.1, D9.1 (K), L1.2, R4.2, TP6.1, U1.3 (FB), U2.3 (VIN), U7.3 (VCC)
+BATT: TP8.1; also elsewhere on the board
/MPPT_Boost_Converter/BOOST_DRV: U3.17 (PA7); also elsewhere on the board
/MPPT_Boost_Converter/BOOST_EN: U3.16 (PA6); also elsewhere on the board
/MPPT_Boost_Converter/V_SENSE_OUT: U3.13 (PA3); also elsewhere on the board
/MPPT_Boost_Converter/~ALERT_ISENS: U3.26 (PB13); also elsewhere on the board
/Microcontroller/BOOT0: R5.1, U3.44 (BOOT0)
/Microcontroller/BOOT1: R6.1, U3.20 (PB2)
/Microcontroller/BTN1: R11.1, SW4.2, U3.39 (PB3)
/Microcontroller/BTN2: R12.1, SW5.2, U3.40 (PB4)
/Microcontroller/CANH: J3.1, JP1.1 (A), U7.7 (CANH)
/Microcontroller/CANL: J3.2, R22.1, U7.6 (CANL)
/Microcontroller/CAN_RX: U3.45 (PB8), U7.4 (RXD)
/Microcontroller/CAN_STB: U3.41 (PB5), U7.8 (STB)
/Microcontroller/CAN_TX: U3.46 (PB9), U7.1 (TXD)
/Microcontroller/DBG_RX: J2.2, U3.31 (PA10)
/Microcontroller/DBG_TX: J2.3, U3.30 (PA9)
/Microcontroller/LED_BLU: R9.2, U3.27 (PB14)
/Microcontroller/LED_GRN: R3.2, U3.28 (PB15)
/Microcontroller/LED_YLW: R10.2, U3.29 (PA8)
/Microcontroller/OSCIN: C10.1, R7.1, U3.5 (PD0), Y2.1
/Microcontroller/OSCOUT: C11.1, R7.2, U3.6 (PD1), Y2.3
/Microcontroller/RESET: C2.1, SW1.2, U3.7 (NRST)
/Microcontroller/RTC_OSC_1: C8.1, U3.3 (PC14), Y1.1
/Microcontroller/RTC_OSC_2: C9.1, U3.4 (PC15), Y1.2
/Microcontroller/SCL_1: R13.1, TP2.1, U3.42 (PB6), U8.1 (SCL); also elsewhere on the board
/Microcontroller/SDA_1: R14.1, TP1.1, U3.43 (PB7), U8.3 (SDA); also elsewhere on the board
/Microcontroller/SWDCLK: P1.3 (SWDCLK), U3.37 (PA14)
/Microcontroller/SWDIO: P1.2 (SWDIO), U3.34 (PA13)
/Microcontroller/USB_DN: TP11.1, U3.32 (PA11)
/Microcontroller/USB_DP: TP10.1, U3.33 (PA12)
GND: C1.2, C2.2, C4.2, C5.2, C6.2, C7.2, C8.2, C9.2, C10.2, C11.2, C12.2, C13.2, C14.2, C15.2, C16.2, C17.2, C18.2, C33.2, C34.2, C35.2, C37.2, D4.1 (K), D5.1 (K), D6.1 (K), D10.1 (K), D11.1 (K), J2.4, NT1.1, P1.4 (GND), SW1.1, SW2.1 (A), SW3.1 (A), SW4.1, SW5.1, TP3.1, TP5.1, TP9.1, U1.2 (GND), U2.1 (GND), U3.23 (VSS), U3.35 (VSS), U3.47 (VSS), U7.2 (GND), U8.2 (GND), U8.5 (WP), Y2.2, Y2.4; also elsewhere on the board
GNDA: C36.2, NT1.2, U3.8 (VSSA); also elsewhere on the board
unnamed: C3.1, U1.1 (CB)
unnamed: C3.2, L1.1, U1.6 (SW)
unnamed: D3.2 (A), P1.1 (VCC)
unnamed: D4.2 (A), R8.1
unnamed: D5.2 (A), R3.1
unnamed: D6.2 (A), R9.1
unnamed: D9.2 (A), J2.1
unnamed: D10.2 (A), R10.1
unnamed: D11.2 (A), R4.1
unnamed: JP1.2 (B), R22.2
unnamed: R5.2, SW2.2 (B)
unnamed: R6.2, SW3.2 (B)
PA0: U3.10 (PA0)
PA1: U3.11 (PA1)
PA2: U3.12 (PA2)
PA4: U3.14 (PA4)
PA5: U3.15 (PA5)
PA15: U3.38 (PA15)
PB0: U3.18 (PB0)
PB1: U3.19 (PB1)
VCC: C1.1, TP7.1, U1.4 (EN), U1.5 (VIN); also elsewhere on the board

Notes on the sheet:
CAN Bus Transceiver:
EEPROM:
Power Supply 3.3V
Reset
User Buttons
Analog Power Supply filter:
Microcontroller
SWD Programming Port
Power Supply 5V
Boot Mode
Decoupling
UART Header:
Debug LEDs
I²C Header, Pullups and test points
Oscillator

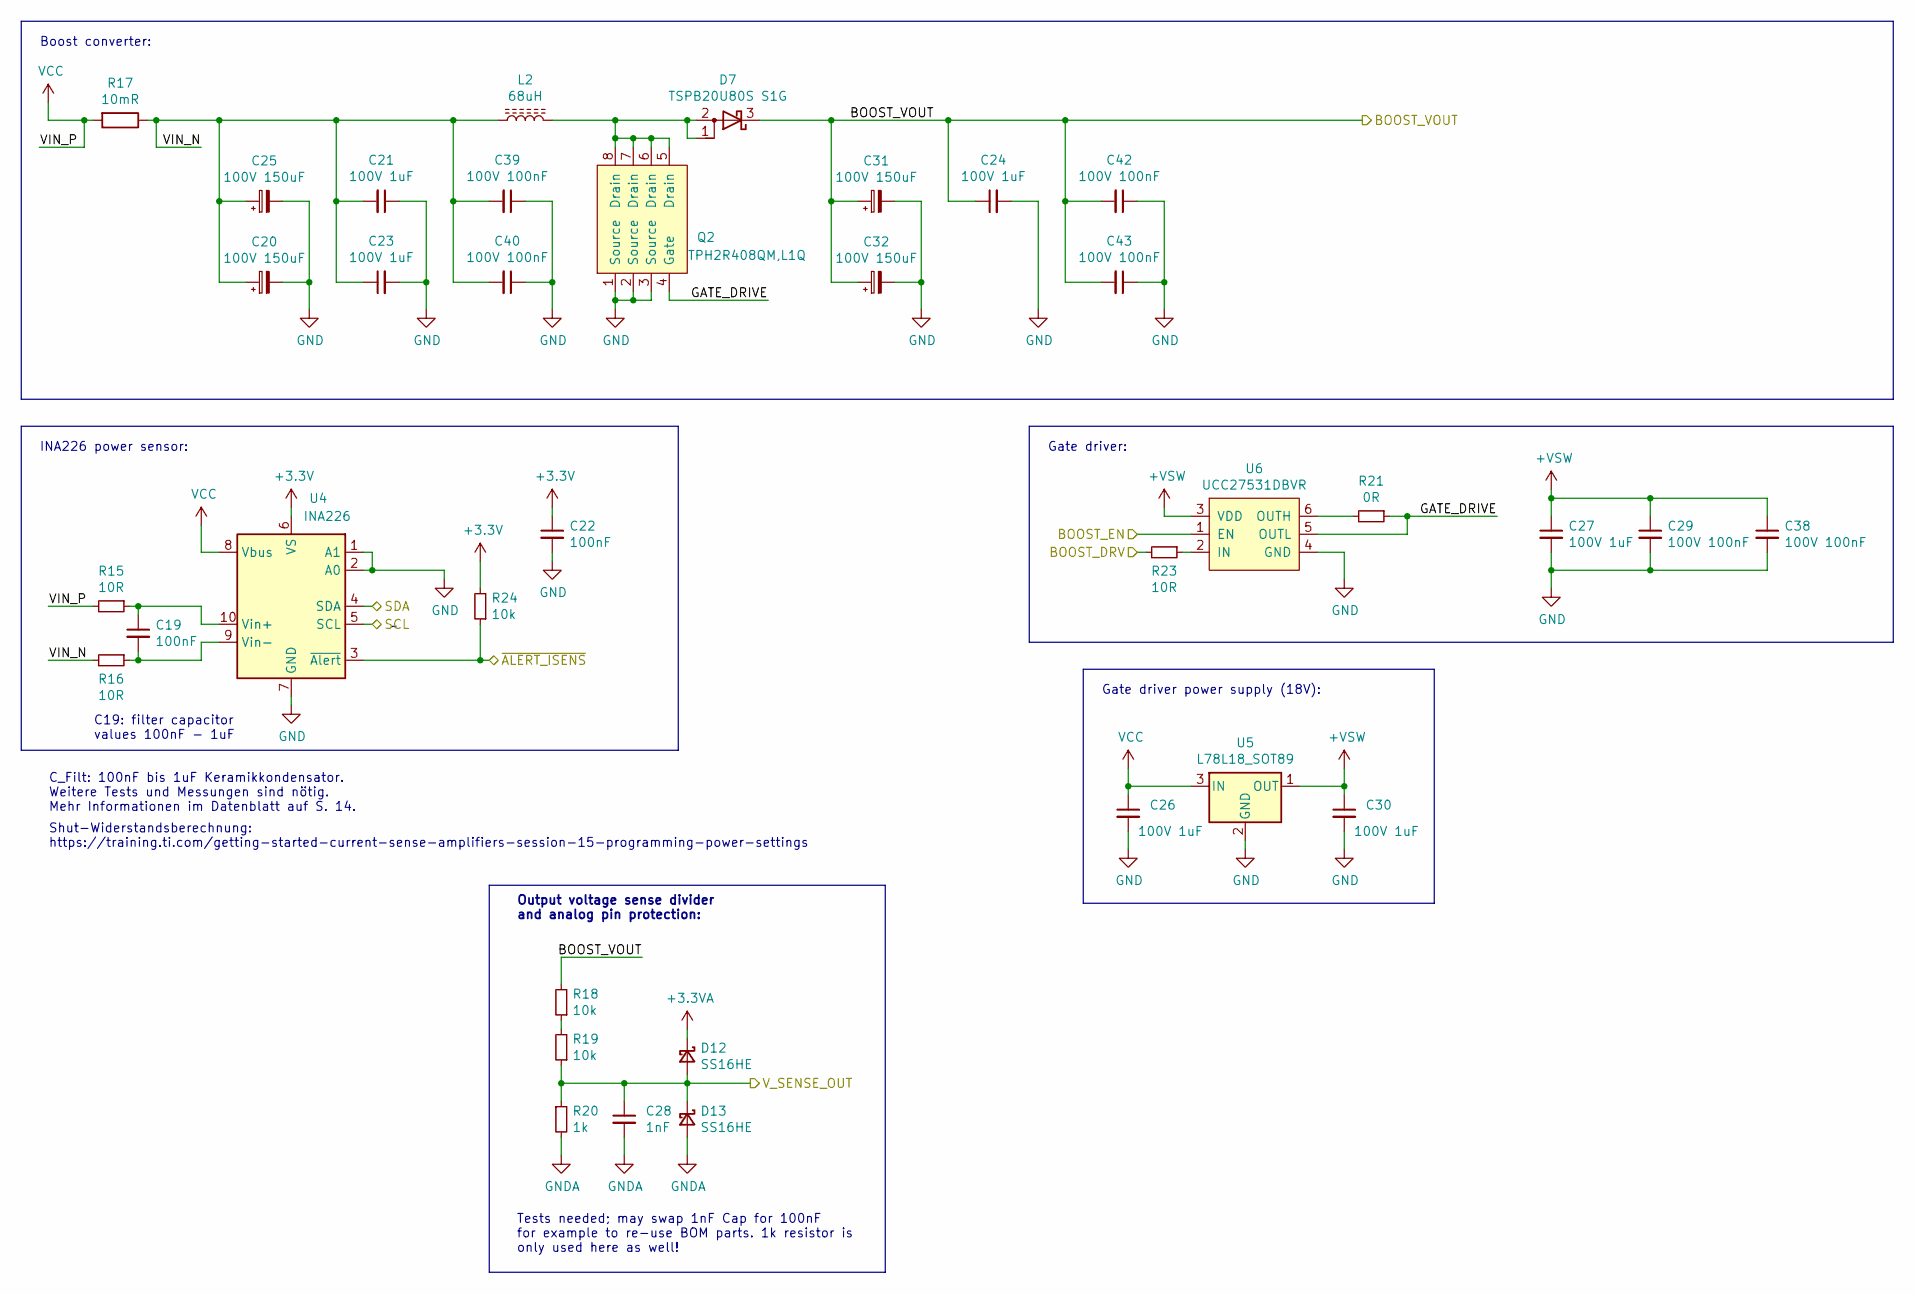
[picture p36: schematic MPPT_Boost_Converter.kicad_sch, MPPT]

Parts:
C19, C22: 100nF; C_0603_1608Metric; Manufacturer Part Number LMK063C6104KP-F; Digikey Part No 1276-CL10B104KB8NNNLCT-ND
C20, C25, C31, C32: 100V 150uF; CAPAE1300X1650N; Manufacturer Part Number EMHS101ARA151MKG5S; Digikey Part No 565-5086-1-ND
C21, C23, C24, C26, C27, C30: 100V 1uF; C_1206_3216Metric; Manufacturer Part Number HMK316BJ105KL-T; Digikey Part No 587-5021-1-ND
C28: 1nF; C_0603_1608Metric; Manufacturer Part Number C0603C102J5RACAUTO; Digikey Part No 399-12989-1-ND
C29, C38, C39, C40, C42, C43: 100V 100nF; C_0603_1608Metric; Manufacturer Part Number CL10B104KC8NNNC; Digikey Part No 587-6323-1-ND
D7: TSPB20U80S S1G; TO-277A; Manufacturer Part Number TSPB20U80S S1G; Digikey Part No TSPB20U80SS1GCT-ND
D12, D13: SS16HE; D_SOD-323; Manufacturer Part Number SS16HE; Digikey Part No SS16HECT-ND
L2: 68uH; 74437429203680; Manufacturer Part Number 74437429203680; Digikey Part No 732-11708-ND
Q2: TPH2R408QM,L1Q; SOP_ADVANCE; Manufacturer Part Number TPH2R408QM,L1Q; Digikey Part No 264-TPH2R408QML1QCT-ND
R15, R16, R23: 10R; R_0603_1608Metric; Manufacturer Part Number RMCF0603FT10R0; Digikey Part No RMCF0603FT10R0CT-ND
R17: 10mR; R_0612_1632Metric; Manufacturer Part Number CFG0612-FX-R010ELF; Digikey Part No CFG0612-FX-R010ELFCT-ND
R18, R19, R24: 10k; R_0603_1608Metric; Manufacturer Part Number RC0603FR-0710KL; Digikey Part No 311-10.0KHRCT-ND
R20: 1k; R_0603_1608Metric; Manufacturer Part Number CRCW06031K00FKEAC; Digikey Part No 541-3949-1-ND
R21: 0R; R_0603_1608Metric; Manufacturer Part Number RC0603FR-070RL; Digikey Part No 311-0.0HRCT-ND
U4: INA226; VSSOP-10_3x3mm_P0.5mm; Manufacturer Part Number INA226AIDGSR; Digikey Part No 296-29034-1-ND
U5: L78L18_SOT89; SOT-89-3; Manufacturer Part Number L78L18ACUTR; Digikey Part No 497-7280-1-ND
U6: UCC27531DBVR; SOT-23-6; Manufacturer Part Number UCC27531DBVR; Digikey Part No 296-35581-1-ND

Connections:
+3.3VA: D12.1 (K); also elsewhere on the board
+3V3: C22.1, R24.2, U4.6 (VS); also elsewhere on the board
+VSW: C27.1, C29.1, C30.1, C38.1, U5.1 (OUT), U6.3 (VDD)
/MPPT_Boost_Converter/BOOST_DRV: R23.2; also elsewhere on the board
/MPPT_Boost_Converter/BOOST_EN: U6.1 (EN); also elsewhere on the board
/MPPT_Boost_Converter/BOOST_VOUT: C24.1, C31.1, C32.1, C42.2, C43.2, D7.3 (K), R18.2; also elsewhere on the board
/MPPT_Boost_Converter/GATE_DRIVE: Q2.4 (Gate), R21.1, U6.5 (OUTL)
/MPPT_Boost_Converter/VIN_N: C20.1, C21.2, C23.1, C25.1, C39.2, C40.2, L2.1, R16.2, R17.1
/MPPT_Boost_Converter/V_SENSE_OUT: C28.1, D12.2 (A), D13.1 (K), R19.1, R20.1; also elsewhere on the board
/MPPT_Boost_Converter/~ALERT_ISENS: R24.1, U4.3 (~Alert); also elsewhere on the board
/Microcontroller/SCL_1: U4.5 (SCL); also elsewhere on the board
/Microcontroller/SDA_1: U4.4 (SDA); also elsewhere on the board
GND: C20.2, C21.1, C22.2, C23.2, C24.2, C25.2, C26.2, C27.2, C29.2, C30.2, C31.2, C32.2, C38.2, C39.1, C40.1, C42.1, C43.1, Q2.1 (Source), Q2.2 (Source), Q2.3 (Source), U4.1 (A1), U4.2 (A0), U4.7 (GND), U5.2 (GND), U6.4 (GND); also elsewhere on the board
GNDA: C28.2, D13.2 (A), R20.2; also elsewhere on the board
unnamed: C19.1, R15.1, U4.10 (Vin+)
unnamed: C19.2, R16.1, U4.9 (Vin-)
unnamed: D7.1 (A), D7.2 (A), L2.2, Q2.5 (Drain), Q2.6 (Drain), Q2.7 (Drain), Q2.8 (Drain)
unnamed: R18.1, R19.2
unnamed: R21.2, U6.6 (OUTH)
unnamed: R23.1, U6.2 (IN)
VCC: C26.1, R15.2, R17.2, U4.8 (Vbus), U5.3 (IN); also elsewhere on the board

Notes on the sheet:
Output voltage sense divider and analog pin protection:
C19: filter capacitor values 100nF - 1uF
Boost converter:
Shut-Widerstandsberechnung: https://training.ti.com/getting-started-current-sense-amplifiers-session-15-programming-power-settings
Gate driver:
Gate driver power supply (18V):
Tests needed; may swap 1nF Cap for 100nF for example to re-use BOM parts. 1k resistor is only used here as well!
INA226 power sensor:
C_Filt: 100nF bis 1uF Keramikkondensator. Weitere Tests und Messungen sind nötig. Mehr Informationen im Datenblatt auf S. 14.

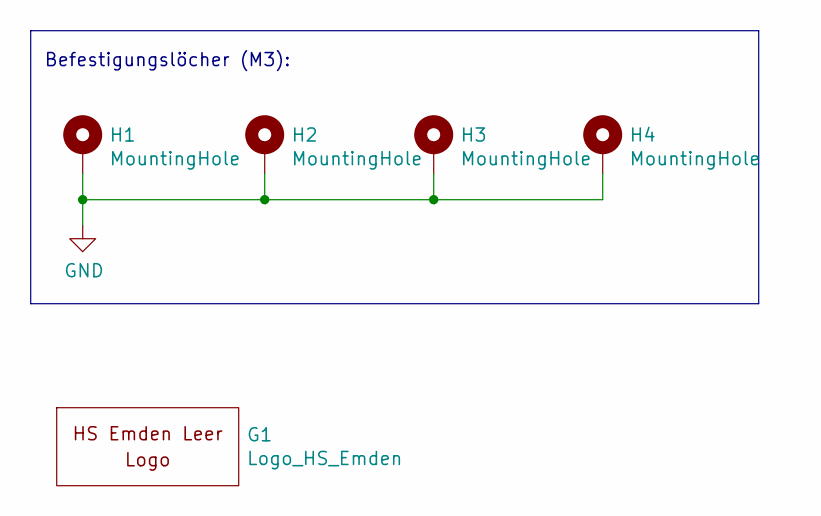
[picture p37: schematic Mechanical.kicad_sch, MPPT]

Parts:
G1: Logo_HS_Emden; HS_Logo
H1, H2, H3, H4: MountingHole; MountingHole_3.2mm_M3_Pad_Via

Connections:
GND: H1.1, H2.1, H3.1, H4.1; also elsewhere on the board

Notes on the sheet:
Befestigungslöcher (M3):

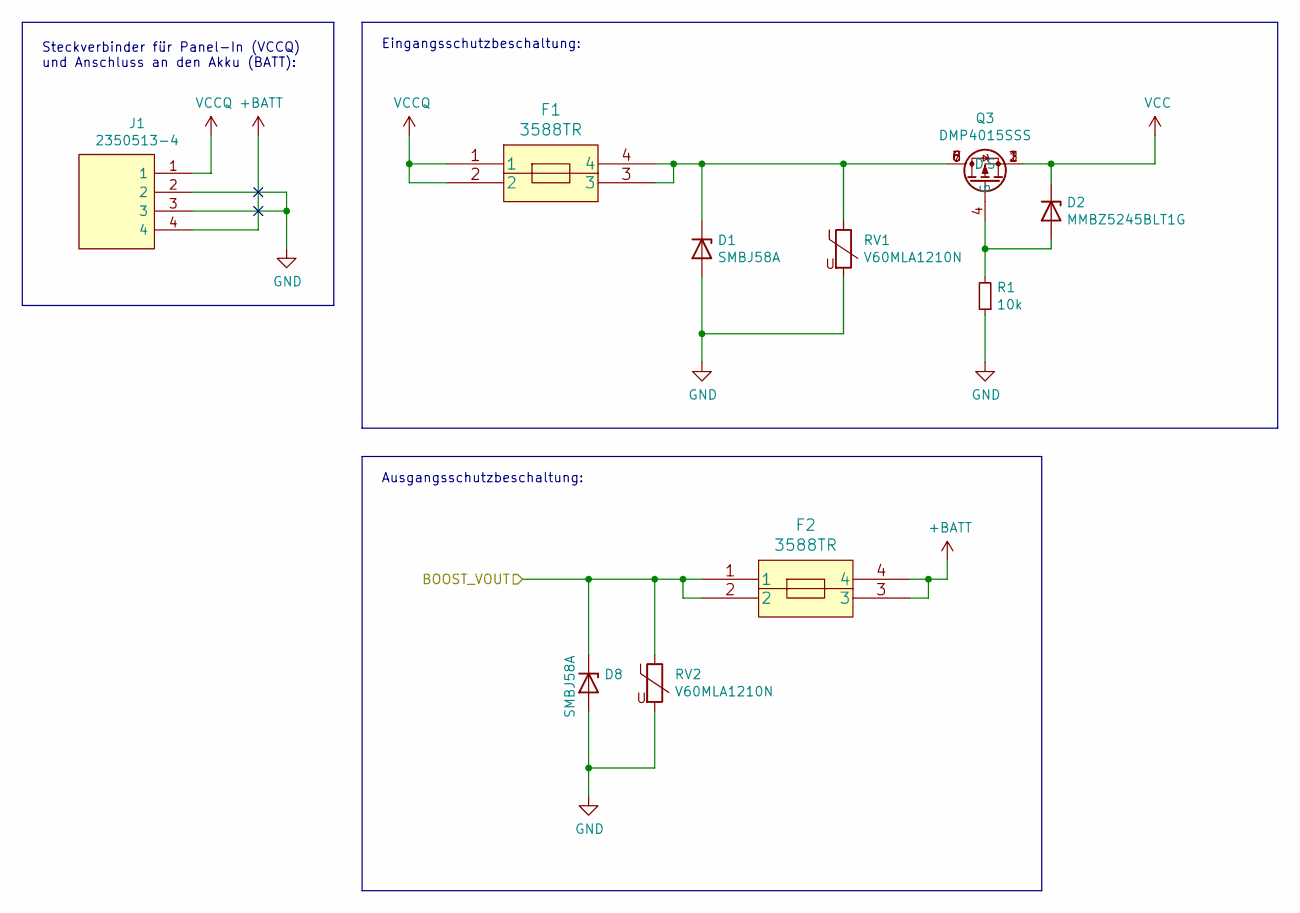
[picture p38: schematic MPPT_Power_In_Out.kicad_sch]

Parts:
D1, D8: SMBJ58A; D_SMB; Manufacturer Part Number SMBJ58A; Digikey Part No SMBJ58ALFCT-ND
D2: MMBZ5245BLT1G; D_SOT-23_ANK; Manufacturer Part Number MMBZ5245BLT1G; Digikey Part No MMBZ5245BLT1GOSCT-ND
F1, F2: 3588TR; Manufacturer Part Number 3588TR; Digikey Part No 36-3588CT-ND
J1: 2350513-4; SHDRRA4W110P0X500_1X4_2160X830X1230P; Manufacturer Part Number 2350513-4; Digikey Part No A145374-ND
Q3: DMP4015SSS; SO-8_3.9x4.9mm_P1.27mm; Manufacturer Part No DMP4015SSS-13; Digi-Key Part No DMP4015SSS-13DICT-ND
R1: 10k; R_0603_1608Metric; Manufacturer Part Number RC0603FR-0710KL; Digikey Part No 311-10.0KHRCT-ND
RV1, RV2: V60MLA1210N; R_1210_3225Metric; Manufacturer Part Number V60MLA1210NH; Digikey Part No F3830CT-ND

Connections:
+BATT: F2.3, F2.4, J1.4; also elsewhere on the board
/MPPT_Boost_Converter/BOOST_VOUT: D8.1 (K), F2.1, F2.2, RV2.1; also elsewhere on the board
GND: D1.2 (A), D8.2 (A), J1.2, J1.3, R1.1, RV1.2, RV2.2; also elsewhere on the board
unnamed: D1.1 (K), F1.3, F1.4, Q3.5 (D), Q3.6 (D), Q3.7 (D), Q3.8 (D), RV1.1
unnamed: D2.2 (A), Q3.4 (G), R1.2
VCC: D2.1 (K), Q3.1 (S), Q3.2 (S), Q3.3 (S); also elsewhere on the board
VCCQ: F1.1, F1.2, J1.1

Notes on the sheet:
Eingangsschutzbeschaltung:
Steckverbinder für Panel-In (VCCQ) und Anschluss an den Akku (BATT):
Ausgangsschutzbeschaltung:

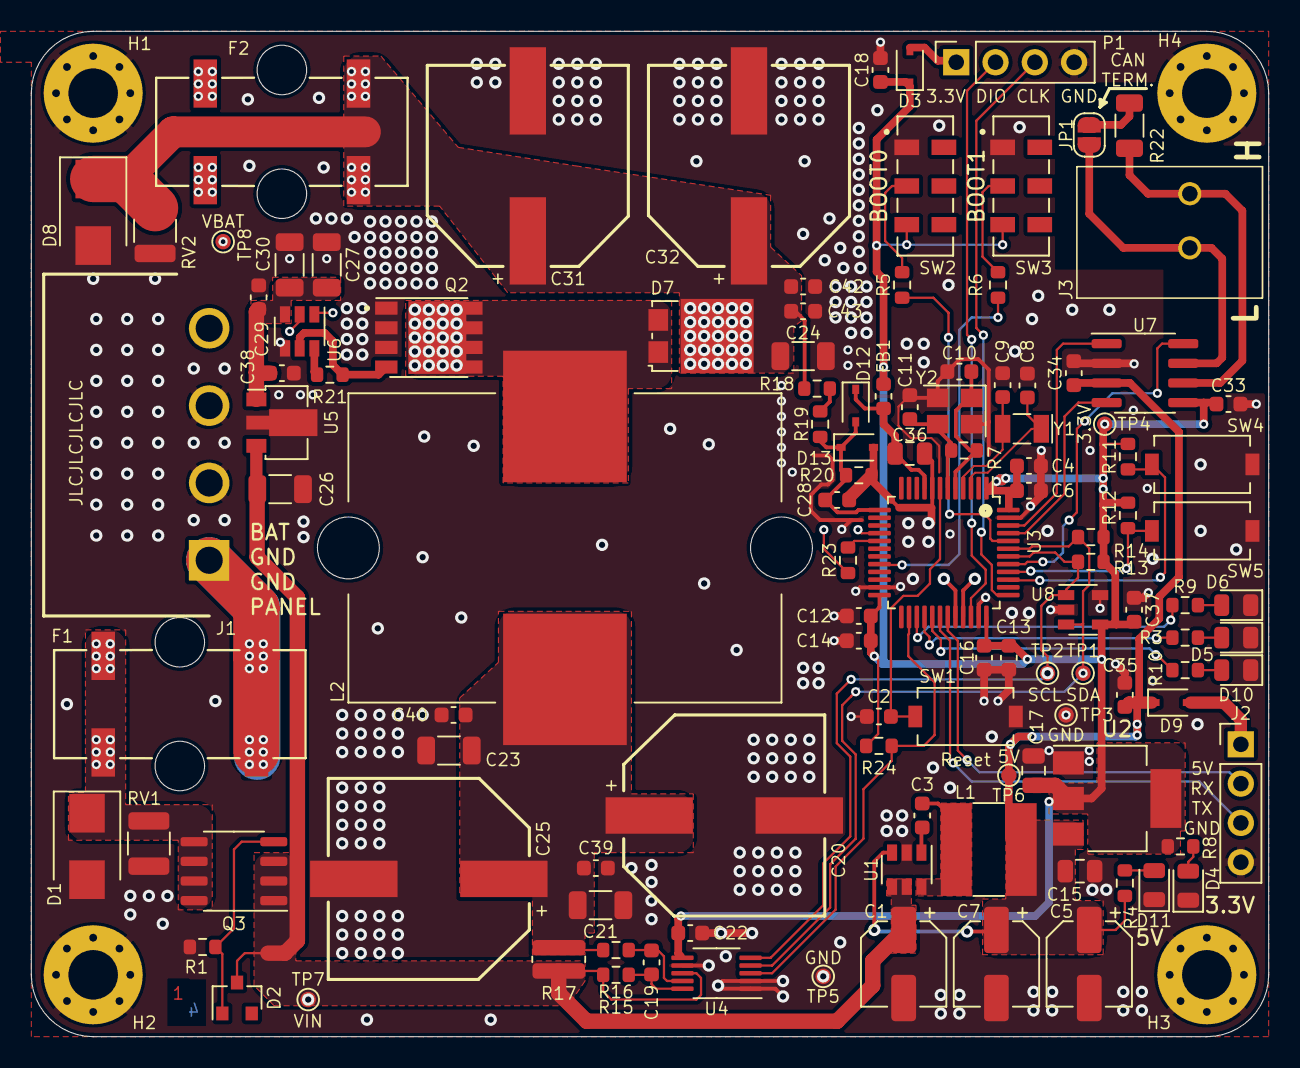
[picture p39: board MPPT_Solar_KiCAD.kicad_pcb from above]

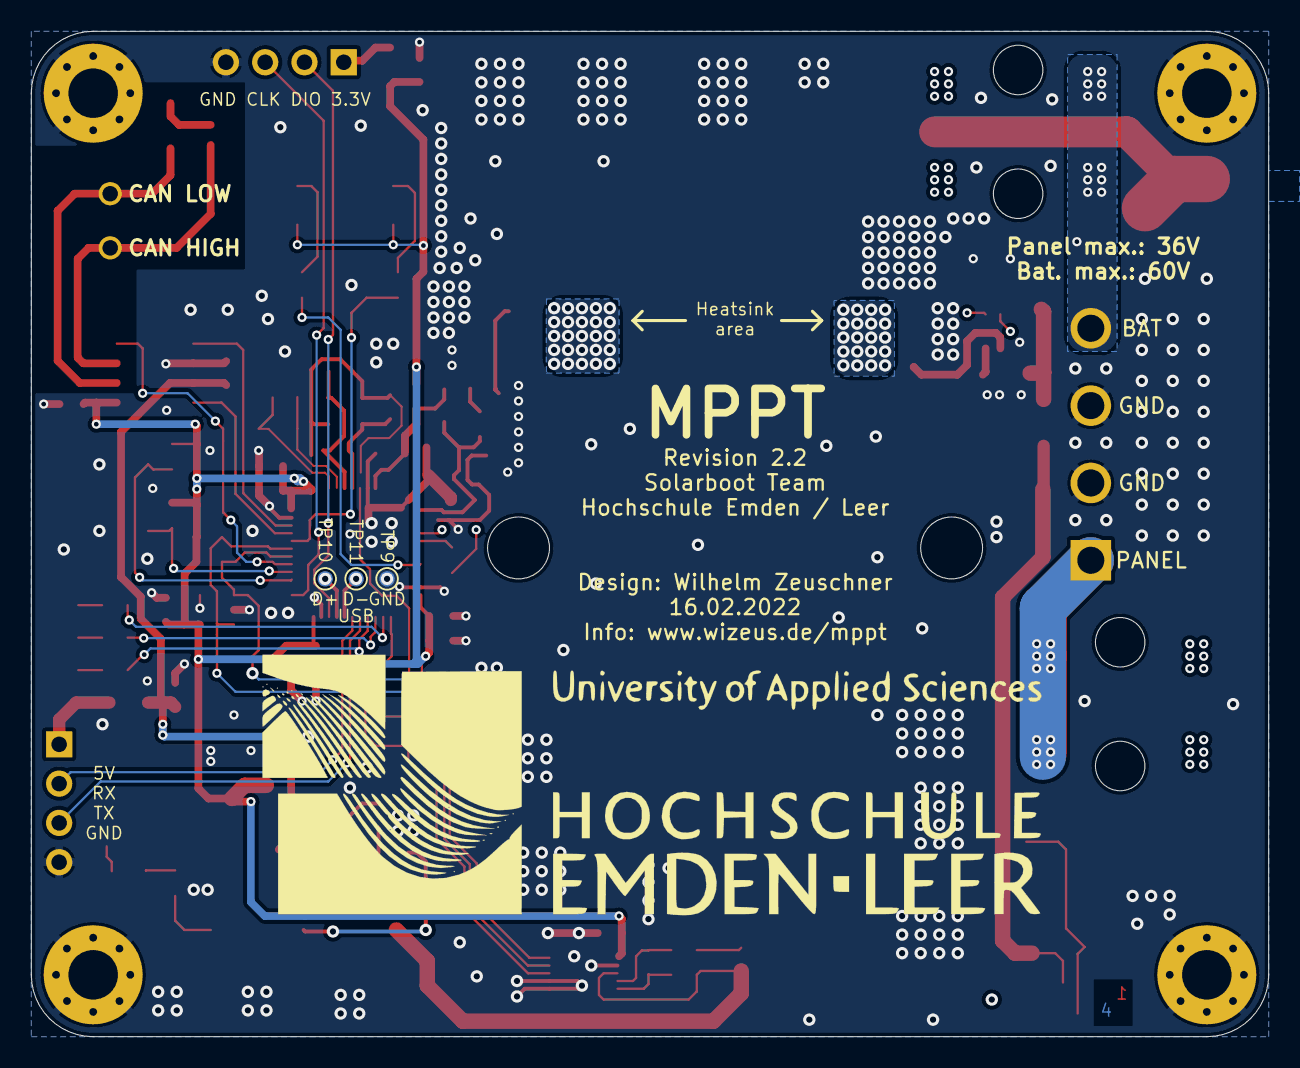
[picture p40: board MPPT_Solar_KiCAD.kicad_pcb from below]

Board: 4 copper layers, 80.0 x 65.0 mm, 124 parts (4 on the bottom side), 61 nets.

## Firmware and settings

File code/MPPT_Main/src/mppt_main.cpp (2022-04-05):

#include <Arduino.h>
#include <Wire.h>

#include <INA.h>

#include "mppt_pins.h"
#include "mppt_config.h"
#include "ina_sensor.h"
#include "mppt_io.h"
#include "mppt_control_algo.h"
#include "mppt_main.h"

INA_Class INA(1); //INA class instantiation to use RAM, one instance

void setup()
{
    static volatile unsigned long mppt_algo_timer = 0;
    mppt_io_init();
    mppt_init_boost_pwm();
    analogReadResolution(MPPT_ADC_RESOLUTION);

    //Serial port
    if (ENABLE_SERIAL_DEBUG)
    {
        DEBUG_SERIAL.begin(DEBUG_SERIAL_BAUD);
        delay(1000);
        DEBUG_SERIAL.println(F("MPPT started."));
    }

    //INA226 power sensor
    ina_begin(INA);


    //Main program loop
    DEBUG_SERIAL.println(F("Starting MPPT algorithm."));
    mppt_boost_enable();
    while (true)
    {
        if (millis() - mppt_algo_timer >= MPPT_ALGORITHM_DELAY) {
            mppt_algo(INA, 1);
            mppt_algo_timer = millis();
            //Serial.println(mppt_algo_timer);
        }
        else {
            mppt_algo(INA, 0);
        }
                
    }
}

//void loop() is no used since it is slower than a simple while(true)
void loop()
{
}

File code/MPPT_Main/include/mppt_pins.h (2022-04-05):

/*
Pin definitions
*/

#ifndef __MPPT_PINS
#define __MPPT_PINS


//LEDs for status indication etc.
#define LED1_PIN        PB_14        //Blue LED
#define LED2_PIN        PB_15        //Green LED
#define LED3_PIN        PA_8         //Red LED
#define LED_BLUE_PIN    LED1_PIN
#define LED_GREEN_PIN   LED2_PIN
#define LED_RED_PIN     LED3_PIN

//Buttons
#define BTN1_PIN        PB_3         //Top (SW4)
#define BTN2_PIN        PB_4         //Bottom (SW5)

//CAN Bus Pins
#define CAN_RX_PIN      PB_8
#define CAN_TX_PIN      PB_9
#define CAN_STBY_PIN    PB_5
#define CAN_STBY_ON     1
#define CAN_STBY_OFF    0

//Boost control pins
#define BOOST_DRIVE_PIN PA_7
#define BOOST_EN_PIN    PA_6
#define BOOST_EN_ON     1
#define BOOST_EN_OFF    0

//Output voltage sensing
#define V_SENSE_OUT_PIN PA_3

//INA226 signals
#define ALERT_ISENS_PIN PB_13        //Overcurrent alert input to STM32
#define SDA_1           PB_7
#define SCL_1           PB_6


#endif

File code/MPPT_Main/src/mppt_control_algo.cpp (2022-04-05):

/*
MPPT algorithm
*/

#include "mppt_control_algo.h"
#include "mppt_pins.h"
#include "ina_sensor.h"
#include "mppt_io.h"
#include "mppt_main.h"

#define MAX(a, b) (((a) > (b)) ? (a) : (b)) // Determine maximum of a and b

/*extern*/ volatile float in_voltage, in_power, in_power_check_max, out_voltage;
volatile float in_power_1, in_power_2, in_power_initial;

/*
This algorithm is pretty simple.
It is based the preturb and observere algorithm to track the maximum power point
Input power gets raised by raising the ouput voltage, respecting the maximum allowed output voltage.

potential issues:
	p&o gets skipped if one of the previous conditions is true -> implement return or ignore?
*/
int mppt_algo(INA_Class &INA, bool run_preturb)
{
	// Reference values for previous power readings (last preturb and observe cycle)
	// These get compared to the new values and based on the result of the comparision the pulse width gets adjusted
	static volatile bool mppt_pwm_change_direction = 0; // 0-> PWM was decreased; 1-> PWM was increased
	static volatile float mppt_prev_in_power = 0;		// Measured input power of the last p&o run

	// Measure current values
	mppt_io_read_output_voltage(MPPT_ADC_READING_AVG_COUNT, out_voltage);
	ina_read_voltage(INA, in_voltage);

	//////////////////////////////////////////////////////////////////
	// FAIL SAFE DETECTIONS BELOW
	//////////////////////////////////////////////////////////////////

	// Last resort fail safe; output voltage is way too high
	if (out_voltage > (MPPT_MAX_OUT_VOLTAGE + 5))
	{

		while (out_voltage > MPPT_MAX_OUT_VOLTAGE)
		{
			mppt_dec_boost_pwm();
			mppt_leds_state(255);
			mppt_io_read_output_voltage(MPPT_ADC_READING_AVG_COUNT, out_voltage);
		}
		DEBUG_SERIAL.println(F("!FAIL MAX VOUT!"));

		return -1;
	}

	// Last resort fail safe; input power is way too high
	ina_read_power_milli_watt(INA, in_power_check_max);
	if (in_power_check_max > (MPPT_MAX_PIN_MILLI_WATT))
	{

		while (in_power_check_max > MPPT_MAX_PIN_MILLI_WATT)
		{
			mppt_dec_boost_pwm();
			// mppt_leds_state(255);
			ina_read_power_milli_watt(INA, in_power_check_max);
		}
		DEBUG_SERIAL.println(F("!FAIL MAX PIN!"));

		return -1;
	}

	// Output Short Circuit Detection
	// If the output voltage is approx. 0V, there has to be a short to GND.
	// Otherwise at least the Panel Voltage is present, since the output is always connected to the input via the main inductor
	mppt_io_read_output_voltage(MPPT_ADC_READING_AVG_COUNT, out_voltage);
	if (out_voltage < 1) {
		//mppt_boost_disable();
		int zero = 0;
		mppt_set_boost_pwm(zero);
		DEBUG_SERIAL.println(F("!FAIL OUTPUT SHORTED!"));
		return -1;
	}

	//////////////////////////////////////////////////////////////////
	// MAIN MPPT CONTROL ALGORITHM
	//////////////////////////////////////////////////////////////////

	// Check that the maximum output voltage is not exceeded
	if (out_voltage > MPPT_MAX_OUT_VOLTAGE)
	{
		mppt_dec_boost_pwm();
		mppt_leds_state(0);

		// Serial.println(F("OUT_V"));
	}
	// Check that the panel voltage is not under the allowed minimum
	else if (in_voltage < MPPT_MIN_IN_VOLTAGE)
	{
		mppt_dec_boost_pwm();
		mppt_leds_state(0);

		// Serial.println(F("PAN_V"));
	}

	// MPPT algorithm (preturb and observe)
	// Runs only with the set frequency (mppt_config.h)
	// The caller specifies if this should run by setting run_preturb to true
	else if (run_preturb)
	{
		// Read the current input power
		ina_read_power_milli_watt(INA, in_power);

		// The pulse width was increased in the previous run
		if (mppt_pwm_change_direction)
		{
			// Check if the input power has increased as well
			// If the power has increased, increase the pulse width further
			if (in_power > mppt_prev_in_power)
			{
				mppt_pwm_change_direction = 1;
				mppt_inc_boost_pwm();
			}
			// If the input power has decreased, start to decrease the pulse width
			else if (in_power < mppt_prev_in_power)
			{
				mppt_pwm_change_direction = 0;
				mppt_dec_boost_pwm();
			}
		}

		// The pulse width was decreased in the previous run
		else
		{
			// Check if the input power has increased
			// If the power has increased, decrease the pulse width further
			if (in_power > mppt_prev_in_power)
			{
				mppt_pwm_change_direction = 0;
				mppt_dec_boost_pwm();
			}
			// If the input power has decreased, start to increase the pulse width
			else if (in_power < mppt_prev_in_power)
			{
				mppt_pwm_change_direction = 1;
				mppt_inc_boost_pwm();
			}
		}

		// Set reference for the next run
		mppt_prev_in_power = in_power;
	}
	return 0;
}

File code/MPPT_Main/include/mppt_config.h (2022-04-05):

/*
Configuration file
*/
#include <Arduino.h>

#ifndef __MPPT_CONFIG
#define __MPPT_CONFIG

//Debug serial (UART)
#define ENABLE_SERIAL_DEBUG true
#define DEBUG_SERIAL        Serial
#define DEBUG_SERIAL_BAUD   115200

//CAN Bus functionality
//(not implemented)
#define ENABLE_CAN_BUS      false

//MPPT related settings
#define MPPT_MAX_OUT_VOLTAGE        50      		//MAXIMUM battery voltage / MPPT output (default 50.2)
#define MPPT_MIN_IN_VOLTAGE         10      		//MINIMUM panel / input voltage
#define MPPT_MAX_PIN_MILLI_WATT		130 * 1000		//MAXIMUM INPUT power, if exceeded, the output voltage will be reduced (safe limit 130W); unit of this define is mW

#define MPPT_ALGORITHM_DELAY        1      	//How often the preturb and observe algorithm gets executed, value is the time (in ms) before the algorithm gets called again => frequency = 1/MPPT_ALGORITHM_DELAY

//Boost converter
#define MPPT_BOOST_MAX_PWM_VAL      1023
#define MPPT_BOOST_MIN_PWM_VAL      0
#define MPPT_BOOST_PWM_RES          RESOLUTION_10B_COMPARE_FORMAT   //"resolution" for PWM
#define MPPT_BOOST_PWM_STEP_SIZE    5

//ADC accuracy / bits for output voltage measurement
#define MPPT_ADC_RESOLUTION             12
const int MPPT_ADC_MAX_READING =        pow(2, MPPT_ADC_RESOLUTION) - 1;
const float MPPT_ADC_REF_VOLTAGE =      3.3;
#define MPPT_ADC_READING_AVG_COUNT      1

//MPPT output voltage divider resistor values
const unsigned int MPPT_OUT_VOLTAGE_R_UPPER = 20000;       //Upper resistor in the divider
const unsigned int MPPT_OUT_VOLTAGE_R_LOWER = 1000;        //Lower resistor in the divider, the ADC measures across this resistor
const unsigned int MPPT_OUT_VOLTAGE_R_SUM = MPPT_OUT_VOLTAGE_R_LOWER + MPPT_OUT_VOLTAGE_R_UPPER;     //Sum of both, makes calculation easier

const float MPPT_OUT_VOLTAGE_DIVIDER_FACTOR = (float)MPPT_OUT_VOLTAGE_R_SUM / (float)MPPT_OUT_VOLTAGE_R_LOWER;

//INA226 current sensor settings
#define MPPT_INA_SHUNT                   10000


#endif
